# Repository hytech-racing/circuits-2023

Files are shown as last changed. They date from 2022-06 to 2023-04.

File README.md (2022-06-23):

HyTech Logo

# 2023 Circuits

Repository for all of the circuits for the 2022-2023 car.

## Getting Started with this Git Repository
1. Follow HyTech's [Software Guide](https://github.com/hytech-racing/training/tree/master/Resources).
2. Create a GitHub account if you don't already have one.
3. Download and install [GitHub Desktop](https://desktop.github.com/) (basic) or [Git CLI](https://git-scm.com/book/en/v2/Getting-Started-Installing-Git) (advanced).
    * If you are using GitHub Desktop for the first time, be sure to read the [User Guide](https://help.github.com/desktop/guides/).
    * If you are using Git for the first time, you should start off by reading a tutorial. There are many available online:
        * [Pro Git book](https://git-scm.com/book/en/v2)
        * [Atlassian Git Tutorial](https://www.atlassian.com/git/tutorials/)
    * You may want to keep a copy of [GitHub's Git Cheat Sheet](https://services.github.com/kit/downloads/github-git-cheat-sheet.pdf) as a reference.
4. Talk to your subteam lead to be added to the team within the GitHub organization.
5. Clone this repository to your computer using the URLs:
    * SSH: `git@github.com:hytech-racing/circuits-2022.git`
    * HTTPS: `https://github.com/hytech-racing/circuits-2022.git`

## Getting Started with EAGLE
1. Follow HyTech's [Software Guide](https://github.com/hytech-racing/training/tree/master/Resources).
2. Download and install [EAGLE](https://www.autodesk.com/products/eagle/overview)
3. Get the free [Educational License](https://www.autodesk.com/education/free-software/eagle) (a .edu email address is required)

## Github Software Guidelines and Electrical Designs Rules Review Process
Follow HyTech's [Github Software Guidelines](https://gtvault.sharepoint.com/:w:/r/sites/HyTechRacing2/Shared%20Documents/Electrical%20-%20All/HT06/Guidelines%20Rules%20and%20Procedures/Github%20Software%20Guide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) to understand our development flow and pull request procedure.
Follow HyTech's [Electrical Designs Rules Review Process](https://gtvault.sharepoint.com/:w:/r/sites/HyTechRacing2/Shared%20Documents/Electrical%20-%20All/HT06/Guidelines%20Rules%20and%20Procedures/Electrical%20Designs%20Ru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) to understand circuit design flow. 

## Circuit Board Versioning Scheme
* New boards must start their numbering at revision 1.
* Revision numbers must be incremented by 1 when a physical board is manufactured, but not at any other time.
* After a board is manufactured, the files corresponding to the manufactured version should not be modified.
* Circuit boards based off of a previous year's design should increment based off of the previous board's revision number.

## More Information
* [Software Guide](https://github.com/hytech-racing/training/tree/master/Resources)
* [Team Site](https://hytechracing.gatech.edu/)
* [Facebook](https://www.facebook.com/HyTechRacing/)
* [Engage](https://gatech.campuslabs.com/engage/organization/hytech-racing)

## License
This project is licensed under the GPL License v3.0. See the [LICENSE](LICENSE) file for more information.

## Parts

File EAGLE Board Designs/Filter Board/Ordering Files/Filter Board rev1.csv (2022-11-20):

Board Quantity | Ordering Quantity | Value | Reference | ATTRITION | CAPACITANCE | DKPN | MANUFACTURER | MOPN | MPN | POWER | RESISTANCE | TOLERANCE | VOLTAGE | VOLTAGE_CONTINUOUS | VOLTAGE_MAX
24 | 34 | CAPACITOR_0603_10V_0.1UF | C25, C27, C29, C31, C33, C35, C37, C39, C41, C43, C45, C47, C81, C83, C85, C87, C89, C91, C93, C95, C97, C99, C101, C103 | 42 | 0.1µF | 720-1688-1-ND | Vishay Vitramon | 77-VJ0603Y104JXQPBC | VJ0603Y104JXQPW1BC |  |  | 5% | 10V
12 | 22 | CAPACITOR_0603_10V_1UF | C26, C30, C34, C38, C42, C46, C82, C86, C90, C94, C98, C102 | 83 | 1µF | 311-1796-1-ND | Yageo | 603-CC603KRX7R6BB105 | CC0603KRX7R6BB105 |  |  | 10% | 10V
12 | 22 | CAPACITOR_0603_10V_680PF | C28, C32, C36, C40, C44, C48, C84, C88, C92, C96, C100, C104 | 83 | 680pF | 732-7757-1-ND | Würth Elektronik | 710-885012006013 | 885012006013 |  |  | 5% | 10V
16 | 26 | CAPACITOR_0603_25V_47NF | C1, C2, C3, C4, C5, C6, C7, C8, C9, C10, C49, C50, C51, C52, C53, C54 | 63 | 47nF | 478-6340-1-ND | Kyocera AVX | 581-06033C473K42ZA | 06033C473K4Z2A |  |  | 10% | 25V
2 | 4 | CONNECTOR-40__ | J4, J5 | 100 |  | SAM8560-ND | Samtec | 200-EHT12001SD | EHT-120-01-S-D
12 | 14 | MAX7400 | U6, U7, U8, U9, U10, U11, U19, U20, U21, U22, U23, U24 | 17 |  | MAX7400CSA+-ND | Maxim Integrated | 700-MAX7400CSA | MAX7400CSA+
12 | 22 | RESISTOR_0603_13K | R4, R9, R11, R13, R15, R17, R27, R35, R37, R39, R41, R43 | 83 |  | P13KBECT-ND | Panasonic Electronic Components | 667-ERA-3ARW133V | ERA-3ARW133V | 0.1W | 13k | 0.05% |  | 75V | 150V
28 | 38 | RESISTOR_0603_3.3K | R1, R2, R3, R5, R6, R7, R8, R10, R12, R14, R16, R18, R19, R20, R21, R22, R23, R24, R25, R26, R28, R29, R30, R36, R38, R40, R42, R44 | 36 |  | P20340TR-ND | Panasonic Electronic Components | 667-ERJ-PB3D3301V | ERJ-PB3D3301V | 0.2W | 3.3k | 0.5% |  | 25.69V | 150

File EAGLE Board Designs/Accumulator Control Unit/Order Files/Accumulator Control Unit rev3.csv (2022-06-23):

Board Quantity | Ordering Quantity | Value | Reference | ATTRITION | CAPACITANCE | COLOR | CURRENT | DKPN | GAUGE | MANUFACTURER | MOPN | MPN | POWER | RESISTANCE | TEENSY | TOLERANCE | VOLTAGE | VOLTAGE_CONTINUOUS | VOLTAGE_MAX
1 | 3 | ADG1423 | U100 | 200 |  |  |  | ADG1423BRMZ-REEL7CT-ND |  | Analog Devices Inc. | 584-ADG1423BRMZ | ADG1423BRMZ
1 | 3 | ADM8316WBX30 | U7 | 200 |  |  |  | ADM8316WBX30ARJZR7TR-ND |  | Analog Devices Inc. | 584-M8316WBX30ARJZR7 | ADM8316WBX30ARJZR7
21 | 31 | CAPACITOR_0603_10V_0.1UF | C3, C5, C9, C10, C11, C13, C14, C15, C16, C17, C18, C19, C21, C22, C26, C27, C28, C30, C31, C34, C38 | 48 | 0.1µF |  |  | 720-1688-1-ND |  | Vishay Vitramon | 77-VJ0603Y104JXQPBC | VJ0603Y104JXQPW1BC |  |  |  | 5% | 10V
3 | 13 | CAPACITOR_0603_10V_10NF | C1, C6, C100 | 333 | 10nF |  |  | 311-4054-1-ND |  | Yageo | 603-CC603KRX7R6BB103 | CC0603KRX7R6BB103 |  |  |  | 10% | 10V
2 | 12 | CAPACITOR_0603_10V_1UF | C37, C39 | 500 | 1µF |  |  | 311-1796-1-ND |  | Yageo | 603-CC603KRX7R6BB105 | CC0603KRX7R6BB105 |  |  |  | 10% | 10V
1 | 11 | CAPACITOR_0603_10V_4.7NF | C25 | 1000 | 4.7nF |  |  | 732-7931-1-ND |  | Würth Elektronik | 710-885012206012 | 885012206012 |  |  |  | 10% | 10V
2 | 12 | CAPACITOR_0603_10V_4.7UF | C36, C103 | 500 | 4.7µF |  |  | 1276-1044-1-ND |  | Samsung Electro-Mechanics | 187-CL10A475KP8NNNC | CL10A475KP8NNNC |  |  |  | 10% | 10V
4 | 14 | CAPACITOR_0603_10V_680PF | C4, C12, C23, C32 | 250 | 680pF |  |  | 732-7757-1-ND |  | Würth Elektronik | 710-885012006013 | 885012006013 |  |  |  | 5% | 10V
6 | 16 | CAPACITOR_0603_25V_0.1UF | C2, C8, C20, C29, C35, C102 | 167 | 0.1µF |  |  | 1276-1006-1-ND |  | Samsung Electro-Mechanics | 187-CL10B104KA8NNNC | CL10B104KA8NNNC |  |  |  | 10% | 25V
2 | 12 | CAPACITOR_0603_25V_10UF | C24, C33 | 500 | 10µF |  |  | 490-7202-1-ND |  | Murata Electronics | 81-GRM188R61E106MA3D | GRM188R61E106MA73D |  |  |  | 20% | 25V
2 | 12 | CAPACITOR_0603_25V_1UF | C101, C104 | 500 | 1µF |  |  | 1276-1184-1-ND |  | Samsung Electro-Mechanics | 187-CL10B105KA8NNNC | CL10B105KA8NNNC |  |  |  | 10% | 25V
1 | 3 | CONNECTOR-12_MF_T_V_ | J5 | 200 |  |  |  |  |  | MOLEX |  | 430451214
1 | 3 | CONNECTOR-14_MF_T_V_ | J3 | 200 |  |  |  |  |  | MOLEX |  | 430451414
1 | 3 | CONNECTOR-2_MF_T_V_ | J1 | 200 |  |  |  |  |  | MOLEX |  | 436500217
1 | 3 | CONNECTOR-8_MF_T_V_ | J2 | 200 |  |  |  |  |  | MOLEX |  | 430450814
1 | 3 | CONNECTOR-8_S_S | J100 | 200 |  |  |  | S7107-ND |  | Sullins Connector Solutions |  | PPPC042LFBN-RC
1 | 3 | CONNECTOR-CAN_μF_S_RA_ | J6 | 200 |  |  |  | WM1832CT-ND |  | Molex | 538-43045-0411 | 0430450411
24 | 48 | CRIMP_MICROFIT_20-24 | O4, O5, O6, O7, O8, O9, O10, O11, O12, O13, O14, O15, O16, O17, O18, O19, O20, O21, O22, O23, O24, O25, O26, O27 | 100 |  |  |  | WM2776CT-ND | 20-24 | Molex | 538-43030-0003 | 0430300003
2 | 4 | FUSE_0603_.75A | F1, F2 | 100 |  |  | 0.75A | 507-2159-2-ND |  | Bel Fuse | 530-0686F0750-01 | 0686F0750-01 |  |  |  |  | 63V
1 | 3 | FUSE_HOLDER_MINIBLADEPTH | XF1 | 200 |  |  |  | 36-3568-ND |  | Keystone | 534-3568 | 3568
1 | 2 | FUSE_MINI_BLADE_1 | O28 | 100 |  |  |  | 2298-ANM58-1A-ND |  | OptiFuse |  | ANM58-1A
1 | 3 | JUMPER__1X02 | J4 | 200 |  |  |  | S1011EC-02-ND |  | Sullins Connector Solutions |  | PRPC002SAAN-RC
2 | 12 | LED_0603_BLUE | 5V, WATCHDOG | 500 |  | Blue |  | 754-1789-1-ND |  | Kingbright | 604-APT1608VBC/D | APT1608VBC/D
3 | 13 | LED_0603_GREEN | 3.3V, AMS_OK, TSAL_GREEN | 333 |  | Green |  | 754-1790-1-ND |  | Kingbright | 604-APT1608ZGCK | APT1608ZGCK
1 | 11 | LED_0603_ORANGE | IMD_OK | 1000 |  | Orange |  | 754-1120-1-ND |  | Kingbright | 604-APT1608SECK | APT1608SECK
4 | 14 | LED_0603_RED | 12V, PRECHARGE_OK, TEENSY_OK, TSAL_RED | 250 |  | Red |  | 754-1786-1-ND |  | Kingbright | 604-APT1608SECKJ3PRV | APT1608SECK/J3-PRV
1 | 2 | LED_0603_YELLOW | OKHS | 100 |  | Yellow |  | 754-1788-1-ND |  | Kingbright | 604-APT1608SYCK/J3-PRV | APT1608SYCK/J3-PRV
1 | 3 | LM555 | U101 | 200 |  |  |  | LM555CMX/NOPBCT-ND |  | Texas Instruments | 926-LM555CMX/NOPB | LM555CMX/NOPB
3 | 5 | LOGICGATE_AND_DCK3 | U12, U14, U16 | 67 |  |  |  | 296-SN74LVC1G08DCK3TR-ND |  | Texas Instruments | 595-SN74LVC1G08DCK3 | SN74LVC1G08DCK3
1 | 3 | LOGICGATE_BUFFER | U6 | 200 |  |  |  | 296-26604-2-ND |  | Texas Instruments | 595-SN74LVC1G34DCKT | SN74LVC1G34DCKT
1 | 3 | LTC6820 | U5 | 200 |  |  |  |  |  | Analog Devices |  | LTC6820IMS#PBF
4 | 6 | MAX7404 | U4, U10, U19, U25 | 50 |  |  |  | MAX7404CSA+-ND |  | Maxim Integrated | 700-MAX7404CSA | MAX7404CSA+
12 | 14 | OPAMP_1_CHANNEL_OPA991 | U3, U9, U11, U13, U15, U17, U18, U20, U21, U22, U23, U24 | 17 |  |  |  | 296-OPA991IDCKRCT-ND |  | Texas Instruments | 595-OPA991IDCKR | OPA991IDCKR
1 | 2 | RECEPTACLE-12_MICROFIT | O3 | 100 |  |  |  | WM1788-ND |  | Molex | 538-43025-1200 | 430251200
1 | 2 | RECEPTACLE-14_MICROFIT | O2 | 100 |  |  |  | 0430251400 |  | Molex | 538-43025-1400 | 430251400
1 | 2 | RECEPTACLE-8_MICROFIT | O1 | 100 |  |  |  | WM13210-ND |  | Molex | 538-43025-0808 | 0430250808
3 | 5 | RELAY_SOLIDSTATE_NO | U1, U2, U8 | 67 |  |  |  |  |  |  |  | AQY214EHA
5 | 15 | RESISTOR_0603_ | R4, R20, R79, R108, R110 | 200 |  |  |  | P30KBDCT-ND |  | Panasonic Electronic Components | 667-ERA-3ARB303V | ERA-3ARB303V | 0.1W | 30k |  | 0.1% |  | 54.77V | 75V
1 | 11 | RESISTOR_0603_1.4K | R58 | 1000 |  |  |  | 311-2465-1-ND |  | Yageo | 603-RT0603DRE071K4L | RT0603DRE071K4L | 0.1W | 1.4K |  | 0.5% |  | 75V | 75V
4 | 14 | RESISTOR_0603_10 | R13, R18, R103, R104 | 250 |  |  |  | 311-10.0HRCT-ND |  | Yageo | 603-RC0603FR-0710RL | RC0603FR-0710RL | 0.1W | 10 |  | 1% |  | 1V | 75V
2 | 12 | RESISTOR_0603_10.2K | R41, R48 | 500 |  |  |  | P10.2KDBCT-ND |  | Panasonic Electronic Components | 667-ERA-3AEB1022V | ERA-3AEB1022V | 0.1W | 10.2k |  | 0.1% |  | 31.94V | 75V
4 | 14 | RESISTOR_0603_10.5K | R65, R68, R72, R76 | 250 |  |  |  | P10.5KDBCT-ND |  | Panasonic Electronic Components | 677-ERA-3AEB1052V | ERA-3AEB1052V | 0.1W | 10.5k |  | 0.1% |  | 32.40V | 75V
27 | 37 | RESISTOR_0603_10K | R6, R12, R14, R17, R22, R26, R27, R29, R30, R37, R42, R43, R44, R50, R52, R55, R59, R69, R71, R73, R77, R81, R82, R100, R101, R102, R106 | 37 |  |  |  | 311-10.0KHRCT-ND |  | Yageo | 603-RC0603FR-0710KL | RC0603FR-0710KL | 0.1W | 10k |  | 1% |  | 31.62V | 75V
1 | 11 | RESISTOR_0603_11.3K | R70 | 1000 |  |  |  | P11.3KDBCT-ND |  | Panasonic Electronic Components | 667-ERA-3AEB1132V | ERA-3AEB1132V | 0.1W | 11.3k |  | 0.1% |  | 33.62V | 75V
7 | 17 | RESISTOR_0603_11.5K | R38, R51, R53, R66, R67, R74, R75 | 143 |  |  |  | P11.5KDBCT-ND |  | Panasonic Electronic Components | 667-ERA-3AEB1152V | ERA-3AEB1152V | 0.1W | 11.5k |  | 0.1% |  | 33.91V | 75V
1 | 11 | RESISTOR_0603_120 | R1 | 1000 |  |  |  | P120DBCT-ND |  | Panasonic Electronic Components | 667-ERA-3AEB121V | ERA-3AEB121V | 0.1W | 120 |  | 0.1% |  | 3.46V | 75V
7 | 17 | RESISTOR_0603_12K | R5, R23, R31, R56, R78, R80, R107 | 143 |  |  |  | 311-12.0KHRCT-ND |  | Yageo | 603-RC0603FR-0712KL | RC0603FR-0712KL | 0.1W | 12k |  | 1% |  | 34.64V | 75V
1 | 11 | RESISTOR_0603_15K | R21 | 1000 |  |  |  | P15KBDCT-ND |  | Panasonic Electronic Components | 667-ERA-3ARB153V | ERA-3ARB153V | 0.1W | 15k |  | 0.1% |  | 38.73V | 75V
1 | 11 | RESISTOR_0603_18.7K | R109 | 1000 |  |  |  | 311-18.7KHRCT-ND |  | Yageo | 603-RC0603FR-0718K7L | RC0603FR-0718K7L | 0.1W | 18.7k |  | 1% |  | 43.24V | 75V
9 | 19 | RESISTOR_0603_1K | R3, R9, R10, R11, R16, R19, R24, R25, R57 | 111 |  |  |  | 311-1.00KHRCT-ND |  | Yageo | 603-RC0603FR-071KL | RC0603FR-071KL | 0.1W | 1k |  | 1% |  | 10.00V | 75V
1 | 11 | RESISTOR_0603_2.2K | R15 | 1000 |  |  |  | 13-RC0603DR-072K2LCT-ND |  | Yageo | 603-RC0603DR-072K2L | RC0603DR-072K2L | 0.1W | 2.2k |  | 0.5% |  | 75V | 75V
1 | 11 | RESISTOR_0603_215K | R46 | 1000 |  |  |  | P215KDBCT-ND |  | Panasonic Electronic Components | 667-ERA-3AEB2153V | ERA-3AEB2153V | 0.1W | 215k |  | 0.1% |  | 75V | 75V
7 | 17 | RESISTOR_0603_2K | R2, R7, R8, R32, R33, R61, R62 | 143 |  |  |  | P2.0KBDCT-ND |  | Panasonic Electronic Components | 667-ERA-3ARB202V | ERA-3ARB202V | 0.1W | 2k |  | 0.1% |  | 14.14V | 75V
2 | 12 | RESISTOR_0603_4.12K | R49, R63 | 500 |  |  |  | P4.12KDBCT-ND |  | Panasonic Electronic Components | 667-ERA-3AEB4121V | ERA-3AEB4121V | 0.1W | 4.12k |  | 0.1% |  | 20.30V | 75V
1 | 11 | RESISTOR_0603_43K | R105 | 1000 |  |  |  | 311-43.0KHRCT-ND |  | Yageo | 603-RC0603FR-0743KL | RC0603FR-0743KL | 0.1W | 43k |  | 1% |  | 65.57V | 75V
3 | 13 | RESISTOR_0603_470 | R28, R34, R35 | 333 |  |  |  | P470BYCT-ND |  | Panasonic Electronic Components | 667-ERJ-PA3F4700V | ERJ-PA3F4700V | 0.25W | 470 |  | 1% |  | 10.84V | 150V
2 | 12 | RESISTOR_0603_60.4 | R36, R60 | 500 |  |  |  | 311-60.4HRCT-ND |  | Yageo | 603-RC0603FR-0760R4L | RC0603FR-0760R4L | 0.1W | 60.4 |  | 1% |  | 2.48V | 75V
1 | 11 | RESISTOR_0603_84.5K | R39 | 1000 |  |  |  | P84.5KDBCT-ND |  | Panasonic Electronic Components | 667-ERA-3AEB8452V | ERA-3AEB8452V | 0.1W | 84.5k |  | 0.1% |  | 75V | 75V
5 | 15 | RESISTOR_0603_DNP | R40, R45, R47, R54, R64 | 200 |  |  |  |  |  |  |  |  |  | DNP
1 | 3 | TCAN1051HQV-Q1 | U27 | 200 |  |  |  | 296-49935-1-ND |  | Texas Instruments | 595-TCAN1051HGVDQ1 | TCAN1051HGVDRQ1
1 | 3 | TEENSY_4.0 | A2 | 200 |  |  |  |  |  |  |  |  |  |  | 4.0
17 | 19 | TEST_POINT | BSPD_CURRENT, CURRENT_REF, CURRENT_SENSE, PACK+_OUT_TEST, PRECHARGE_OK_TEST, TD+, TD-, TP_3.3V, TP_5V, TP_12V, TP_AMS_OK, TP_GND, TP_IMD_OK, TP_TSAL_GREEN, TP_TSAL_RED, TS+_OUT_TEST, WATCHDOG_OK | 12 |  |  |  | 36-5015CT-ND |  | Keystone Electronics | 534-5015 | 5015
1 | 3 | TRANSFORMER_HM2112ZNLT_AIRGAP | T1 | 200 |  |  |  | 1840-1036-1-ND |  | Pulse Electronics | 673-HM2112ZNLT | HM2112ZNLT
4 | 6 | TRANSISTOR_N_MOS__PMV15ENEA | Q1, Q2, Q100, Q101 | 50 |  |  |  | 1727-8588-1-ND |  | Nexperia USA Inc. | 771-PMV15ENEAR | PMV15ENEAR
8 | 10 | TVS_15V | D3, D7, D8, D9, D10, D11, D100, D101 | 25 |  |  |  | GSOT15-E3-08CT-ND |  | Vishay General Semiconductor - Diodes Division | 78-GSOT15-E3-08 | GSOT15-E3-08 |  |  |  |  | 15V
2 | 4 | TVS_8V | D2, D4 | 100 |  |  |  | GSOT08-E3-08-ND |  | Vishay General Semiconductor - Diodes Division | 78-GSOT08-E3-08 | GSOT08-E3-08 |  |  |  |  | 8V
1 | 3 | VOLTAGE_REGULATOR_MODULE_OKI-78SR_5V | A1 | 200 |  |  |  | 811-2196-5-ND |  | Murata Power Solutions Inc. | 580-OKI78SR5/1.5W36C | OKI-78SR-5/1.5-W36-C
1 | 3 | VOLTAGE_REGULATOR_SOT223_3.3V | U26 | 200 |  |  |  | 497-17239-1-ND |  | STMicroelectronics | 511-LDL1117S33R | LDL1117S33R

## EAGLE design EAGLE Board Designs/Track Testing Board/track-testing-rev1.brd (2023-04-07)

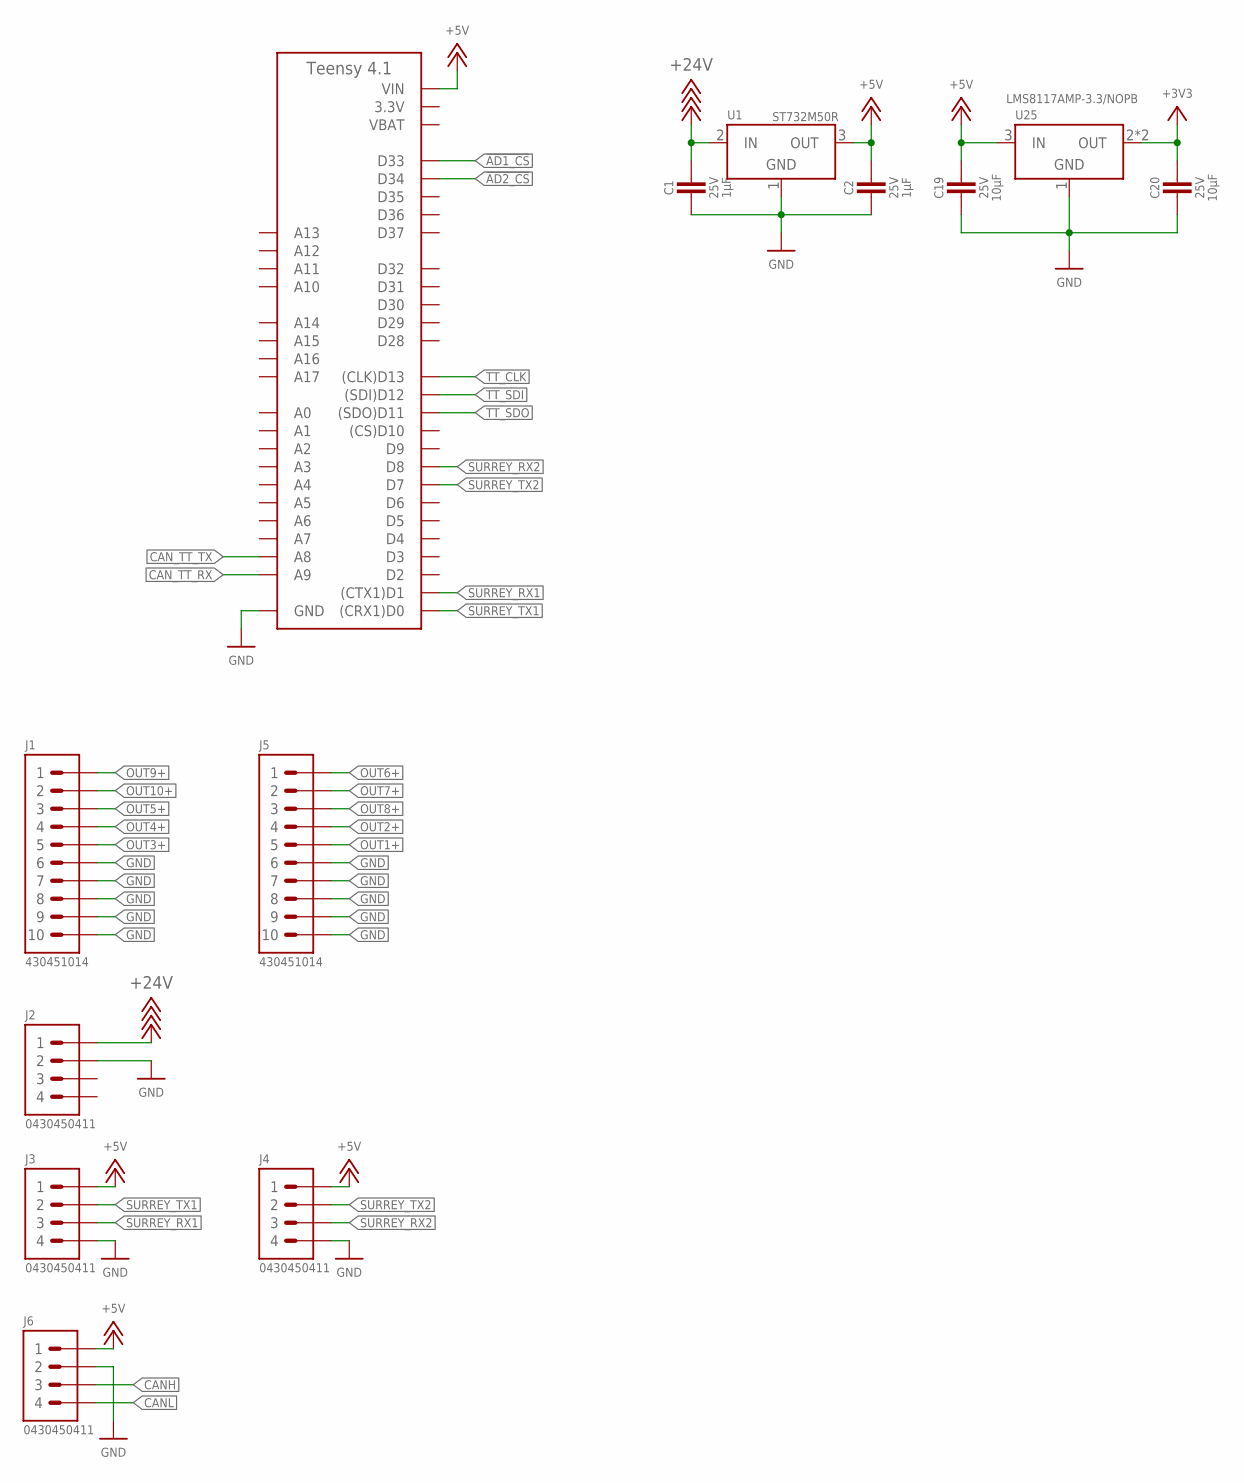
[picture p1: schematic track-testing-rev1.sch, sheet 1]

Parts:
A1: TEENSY_4.1; TEENSY_LONG_EXT
C1, C2: CAPACITOR_0603_25V_1UF; 0603-CAP
C19, C20: CAPACITOR_0603_25V_10UF; 0603-CAP
J1, J5: CONNECTOR-10_MF_T_V_; MOLEX_MICROFIT_PTH_VERTICAL_10_DUAL
J2, J3, J4, J6: CONNECTOR-4_μF_S_RA_; MOLEX_MICROFIT_SMD_RIGHTANGLE_04_DUAL
U1: VOLTAGE_REGULATOR_SOT-23-5_5V; SOT-23-5
U25: VOLTAGE_REGULATOR_SOT-223_3.3V; SOT-223

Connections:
3.3V: A1.3V3 (3.3V), A1.3V3@2 (3.3V), A1.3V3@3 (3.3V)
!AD1_CS: A1.D33; also elsewhere on the board
!AD2_CS: A1.D34; also elsewhere on the board
+3V3: C20.1, U25.2 (OUT), U25.4 (OUT); also elsewhere on the board
+5V: A1.VIN, C2.1, C19.1, J3.1, J4.1, J6.1, U1.3 (OUT), U25.3 (IN); also elsewhere on the board
+24V: C1.1, J2.1, U1.2 (IN)
CANH: J6.3; also elsewhere on the board
CANL: J6.4; also elsewhere on the board
CAN_TT_RX: A1.D23 (A9); also elsewhere on the board
CAN_TT_TX: A1.D22 (A8); also elsewhere on the board
GND: A1.AGND/GND (GND), A1.GND, A1.GND@2 (GND), C1.2, C2.2, C19.2, C20.2, J1.6, J1.7, J1.8, J1.9, J1.10, J2.2, J3.4, J4.4, J5.6, J5.7, J5.8, J5.9, J5.10, J6.2, U1.1 (GND), U25.1 (GND); also elsewhere on the board
OUT1+: J5.5; also elsewhere on the board
OUT2+: J5.4; also elsewhere on the board
OUT3+: J1.5; also elsewhere on the board
OUT4+: J1.4; also elsewhere on the board
OUT5+: J1.3; also elsewhere on the board
OUT6+: J5.1; also elsewhere on the board
OUT7+: J5.2; also elsewhere on the board
OUT8+: J5.3; also elsewhere on the board
OUT9+: J1.1; also elsewhere on the board
OUT10+: J1.2; also elsewhere on the board
SURREY_RX1: A1.D1 ((CTX1)D1), J3.3
SURREY_RX2: A1.D8, J4.3
SURREY_TX1: A1.D0 ((CRX1)D0), J3.2
SURREY_TX2: A1.D7, J4.2
TT_CLK: A1.D13 ((CLK)D13); also elsewhere on the board
TT_SDI: A1.D12 ((SDI)D12); also elsewhere on the board
TT_SDO: A1.D11 ((SDO)D11); also elsewhere on the board
VBAT: A1.VBAT

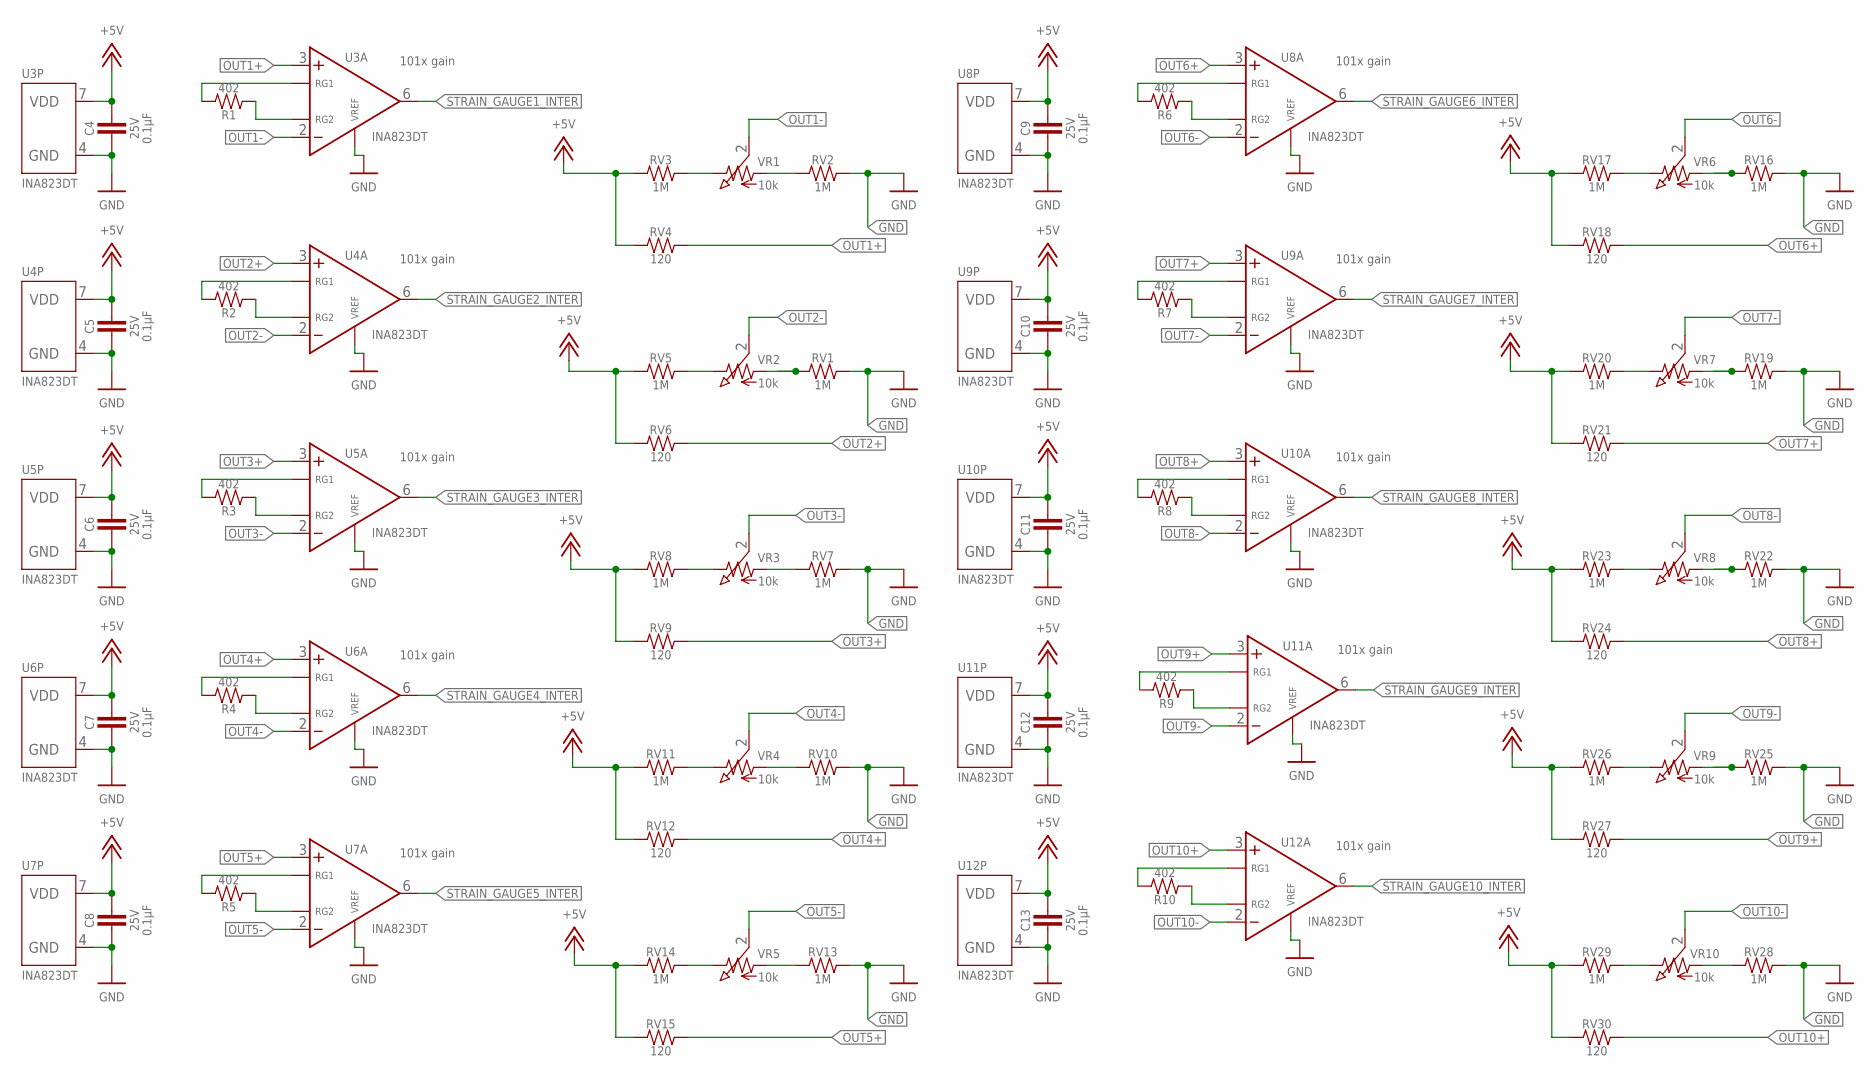
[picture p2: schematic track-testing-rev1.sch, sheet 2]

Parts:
C4, C5, C6, C7, C8, C9, C10, C11, C12, C13: CAPACITOR_0603_25V_0.1UF; 0603-CAP
R1, R2, R3, R4, R5, R6, R7, R8, R9, R10: RESISTOR_0603_402; 0603-RES
RV1, RV2, RV3, RV5, RV7, RV8, RV10, RV11, RV13, RV14, RV16, RV17, RV19, RV20, RV22, RV23, RV25, RV26, RV28, RV29: 1M; 0603-RES
RV4, RV6, RV9, RV12, RV15, RV18, RV21, RV24, RV27, RV30: 120; 0603-RES
U3, U4, U5, U6, U7, U8, U9, U10, U11, U12: INA823DT; SOIC-08(NARROW,0.15")
VR1, VR2, VR3, VR4, VR5, VR6, VR7, VR8, VR9, VR10: RESISTOR_TRIMPOT_10K_3362P; 3362P

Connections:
+5V: C4.1, C5.1, C6.1, C7.1, C8.1, C9.1, C10.1, C11.1, C12.1, C13.1, RV3.1, RV4.1, RV5.1, RV6.1, RV8.1, RV9.1, RV11.1, RV12.1, RV14.1, RV15.1, RV17.1, RV18.1, RV20.1, RV21.1, RV23.1, RV24.1, RV26.1, RV27.1, RV29.1, RV30.1, U3.7 (VDD), U4.7 (VDD), U5.7 (VDD), U6.7 (VDD), U7.7 (VDD), U8.7 (VDD), U9.7 (VDD), U10.7 (VDD), U11.7 (VDD), U12.7 (VDD); also elsewhere on the board
GND: C4.2, C5.2, C6.2, C7.2, C8.2, C9.2, C10.2, C11.2, C12.2, C13.2, RV1.2, RV2.2, RV7.2, RV10.2, RV13.2, RV16.2, RV19.2, RV22.2, RV25.2, RV28.2, U3.4 (GND), U3.5 (VREF), U4.4 (GND), U4.5 (VREF), U5.4 (GND), U5.5 (VREF), U6.4 (GND), U6.5 (VREF), U7.4 (GND), U7.5 (VREF), U8.4 (GND), U8.5 (VREF), U9.4 (GND), U9.5 (VREF), U10.4 (GND), U10.5 (VREF), U11.4 (GND), U11.5 (VREF), U12.4 (GND), U12.5 (VREF); also elsewhere on the board
unnamed: R2.2, U4.1 (RG1)
unnamed: R1.2, U3.1 (RG1)
unnamed: R1.1, U3.8 (RG2)
unnamed: R2.1, U4.8 (RG2)
unnamed: R3.2, U5.1 (RG1)
unnamed: R6.2, U8.1 (RG1)
unnamed: R3.1, U5.8 (RG2)
unnamed: R6.1, U8.8 (RG2)
unnamed: R4.2, U6.1 (RG1)
unnamed: R7.2, U9.1 (RG1)
unnamed: R4.1, U6.8 (RG2)
unnamed: R5.2, U7.1 (RG1)
unnamed: R5.1, U7.8 (RG2)
unnamed: R7.1, U9.8 (RG2)
unnamed: R8.2, U10.1 (RG1)
unnamed: R8.1, U10.8 (RG2)
unnamed: R9.2, U11.1 (RG1)
unnamed: R9.1, U11.8 (RG2)
unnamed: R10.2, U12.1 (RG1)
unnamed: R10.1, U12.8 (RG2)
unnamed: RV2.1, VR1.1
unnamed: RV3.2, VR1.3 (2)
unnamed: RV1.1, VR2.1
unnamed: RV5.2, VR2.3 (2)
unnamed: RV11.2, VR4.3 (2)
unnamed: RV7.1, VR3.1
unnamed: RV8.2, VR3.3 (2)
unnamed: RV10.1, VR4.1
unnamed: RV14.2, VR5.3 (2)
unnamed: RV13.1, VR5.1
unnamed: RV16.1, VR6.1
unnamed: RV17.2, VR6.3 (2)
unnamed: RV19.1, VR7.1
unnamed: RV20.2, VR7.3 (2)
unnamed: RV22.1, VR8.1
unnamed: RV23.2, VR8.3 (2)
unnamed: RV25.1, VR9.1
unnamed: RV26.2, VR9.3 (2)
unnamed: RV28.1, VR10.1
unnamed: RV29.2, VR10.3 (2)
OUT1+: RV4.2, U3.3 (VIN+); also elsewhere on the board
OUT1-: U3.2 (VIN-), VR1.2 (3)
OUT2+: RV6.2, U4.3 (VIN+); also elsewhere on the board
OUT2-: U4.2 (VIN-), VR2.2 (3)
OUT3+: RV9.2, U5.3 (VIN+); also elsewhere on the board
OUT3-: U5.2 (VIN-), VR3.2 (3)
OUT4+: RV12.2, U6.3 (VIN+); also elsewhere on the board
OUT4-: U6.2 (VIN-), VR4.2 (3)
OUT5+: RV15.2, U7.3 (VIN+); also elsewhere on the board
OUT5-: U7.2 (VIN-), VR5.2 (3)
OUT6+: RV18.2, U8.3 (VIN+); also elsewhere on the board
OUT6-: U8.2 (VIN-), VR6.2 (3)
OUT7+: RV21.2, U9.3 (VIN+); also elsewhere on the board
OUT7-: U9.2 (VIN-), VR7.2 (3)
OUT8+: RV24.2, U10.3 (VIN+); also elsewhere on the board
OUT8-: U10.2 (VIN-), VR8.2 (3)
OUT9+: RV27.2, U11.3 (VIN+); also elsewhere on the board
OUT9-: U11.2 (VIN-), VR9.2 (3)
OUT10+: RV30.2, U12.3 (VIN+); also elsewhere on the board
OUT10-: U12.2 (VIN-), VR10.2 (3)
STRAIN_GAUGE1_INTER: U3.6 (VOUT); also elsewhere on the board
STRAIN_GAUGE2_INTER: U4.6 (VOUT); also elsewhere on the board
STRAIN_GAUGE3_INTER: U5.6 (VOUT); also elsewhere on the board
STRAIN_GAUGE4_INTER: U6.6 (VOUT); also elsewhere on the board
STRAIN_GAUGE5_INTER: U7.6 (VOUT); also elsewhere on the board
STRAIN_GAUGE6_INTER: U8.6 (VOUT); also elsewhere on the board
STRAIN_GAUGE7_INTER: U9.6 (VOUT); also elsewhere on the board
STRAIN_GAUGE8_INTER: U10.6 (VOUT); also elsewhere on the board
STRAIN_GAUGE9_INTER: U11.6 (VOUT); also elsewhere on the board
STRAIN_GAUGE10_INTER: U12.6 (VOUT); also elsewhere on the board

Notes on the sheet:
101x gain

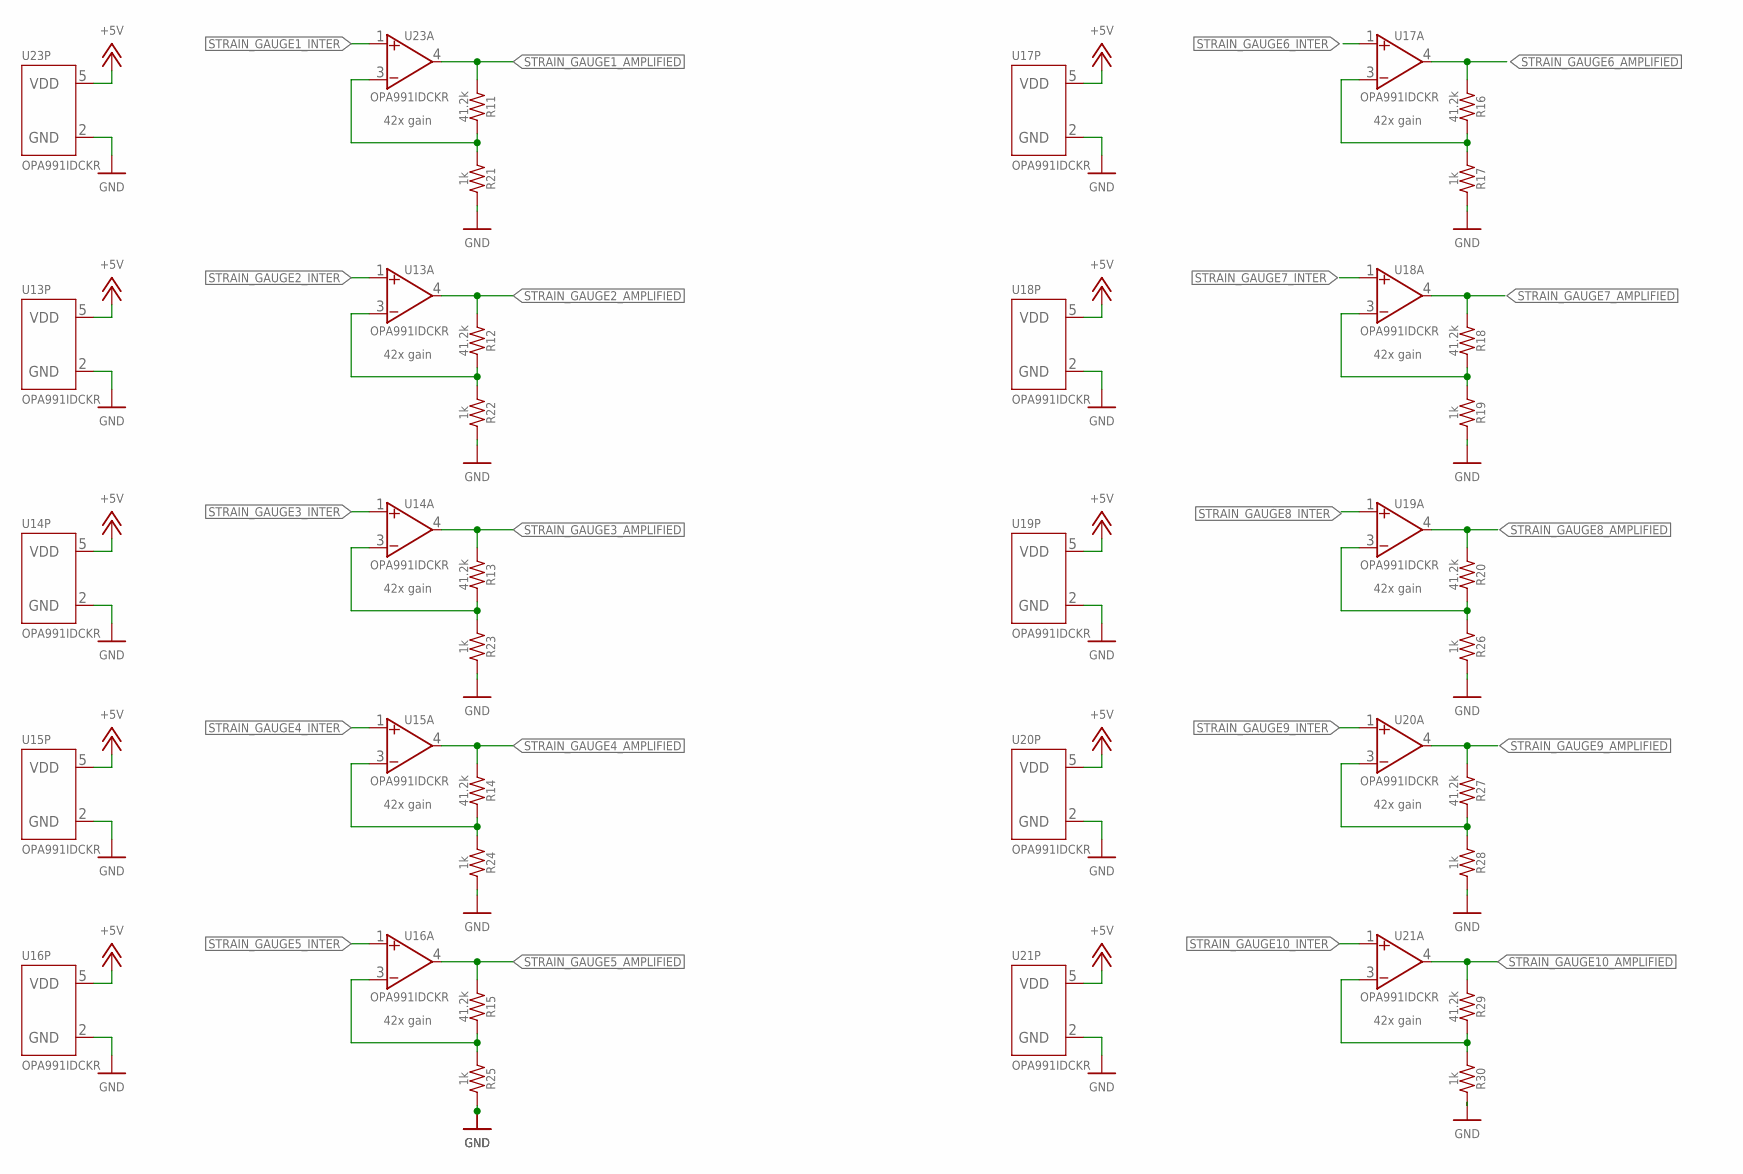
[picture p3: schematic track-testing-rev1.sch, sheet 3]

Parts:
R11, R12, R13, R14, R15, R16, R18, R20, R27, R29: RESISTOR_0603_41.2K; 0603-RES
R17, R19, R21, R22, R23, R24, R25, R26, R28, R30: RESISTOR_0603_1K; 0603-RES
U13, U14, U15, U16, U17, U18, U19, U20, U21, U23: OPAMP_1_CHANNEL_OPA991; SC-70-5

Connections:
+5V: U13.5 (VDD), U14.5 (VDD), U15.5 (VDD), U16.5 (VDD), U17.5 (VDD), U18.5 (VDD), U19.5 (VDD), U20.5 (VDD), U21.5 (VDD), U23.5 (VDD); also elsewhere on the board
GND: R17.2, R19.2, R21.2, R22.2, R23.2, R24.2, R25.2, R26.2, R28.2, R30.2, U13.2 (GND), U14.2 (GND), U15.2 (GND), U16.2 (GND), U17.2 (GND), U18.2 (GND), U19.2 (GND), U20.2 (GND), U21.2 (GND), U23.2 (GND); also elsewhere on the board
unnamed: R12.2, R22.1, U13.3 (VIN-)
unnamed: R11.2, R21.1, U23.3 (VIN-)
unnamed: R13.2, R23.1, U14.3 (VIN-)
unnamed: R14.2, R24.1, U15.3 (VIN-)
unnamed: R15.2, R25.1, U16.3 (VIN-)
unnamed: R16.2, R17.1, U17.3 (VIN-)
unnamed: R18.2, R19.1, U18.3 (VIN-)
unnamed: R20.2, R26.1, U19.3 (VIN-)
unnamed: R27.2, R28.1, U20.3 (VIN-)
unnamed: R29.2, R30.1, U21.3 (VIN-)
STRAIN_GAUGE1_AMPLIFIED: R11.1, U23.4 (VOUT); also elsewhere on the board
STRAIN_GAUGE1_INTER: U23.1 (VIN+); also elsewhere on the board
STRAIN_GAUGE2_AMPLIFIED: R12.1, U13.4 (VOUT); also elsewhere on the board
STRAIN_GAUGE2_INTER: U13.1 (VIN+); also elsewhere on the board
STRAIN_GAUGE3_AMPLIFIED: R13.1, U14.4 (VOUT); also elsewhere on the board
STRAIN_GAUGE3_INTER: U14.1 (VIN+); also elsewhere on the board
STRAIN_GAUGE4_AMPLIFIED: R14.1, U15.4 (VOUT); also elsewhere on the board
STRAIN_GAUGE4_INTER: U15.1 (VIN+); also elsewhere on the board
STRAIN_GAUGE5_AMPLIFIED: R15.1, U16.4 (VOUT); also elsewhere on the board
STRAIN_GAUGE5_INTER: U16.1 (VIN+); also elsewhere on the board
STRAIN_GAUGE6_AMPLIFIED: R16.1, U17.4 (VOUT); also elsewhere on the board
STRAIN_GAUGE6_INTER: U17.1 (VIN+); also elsewhere on the board
STRAIN_GAUGE7_AMPLIFIED: R18.1, U18.4 (VOUT); also elsewhere on the board
STRAIN_GAUGE7_INTER: U18.1 (VIN+); also elsewhere on the board
STRAIN_GAUGE8_AMPLIFIED: R20.1, U19.4 (VOUT); also elsewhere on the board
STRAIN_GAUGE8_INTER: U19.1 (VIN+); also elsewhere on the board
STRAIN_GAUGE9_AMPLIFIED: R27.1, U20.4 (VOUT); also elsewhere on the board
STRAIN_GAUGE9_INTER: U20.1 (VIN+); also elsewhere on the board
STRAIN_GAUGE10_AMPLIFIED: R29.1, U21.4 (VOUT); also elsewhere on the board
STRAIN_GAUGE10_INTER: U21.1 (VIN+); also elsewhere on the board

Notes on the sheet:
42x gain

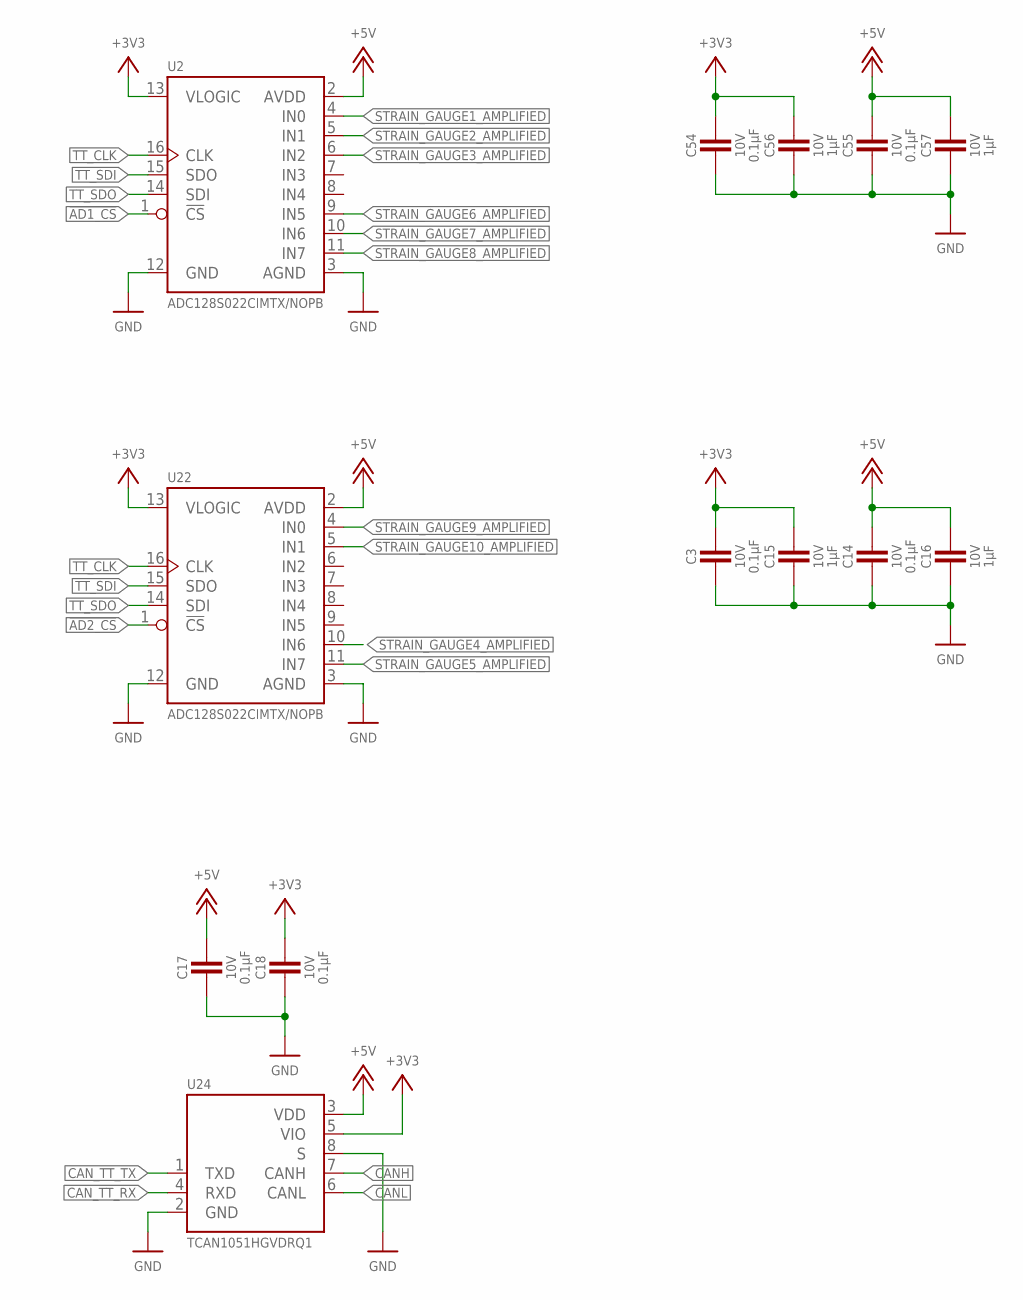
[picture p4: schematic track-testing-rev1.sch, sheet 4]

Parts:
C3, C14, C17, C18, C54, C55: CAPACITOR_0603_10V_0.1UF; 0603-CAP
C15, C16, C56, C57: CAPACITOR_0603_10V_1UF; 0603-CAP
U2, U22: ADC128S022; TSSOP-16
U24: TCAN1051HQV-Q1; SOIC-08(NARROW,0.15")

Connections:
!AD1_CS: U2.1 (!CS!); also elsewhere on the board
!AD2_CS: U22.1 (!CS!); also elsewhere on the board
+3V3: C3.1, C15.1, C18.1, C54.1, C56.1, U2.13 (VLOGIC), U22.13 (VLOGIC), U24.5 (VIO); also elsewhere on the board
+5V: C14.1, C16.1, C17.1, C55.1, C57.1, U2.2 (AVDD), U22.2 (AVDD), U24.3 (VDD); also elsewhere on the board
CANH: U24.7 (CANH); also elsewhere on the board
CANL: U24.6 (CANL); also elsewhere on the board
CAN_TT_RX: U24.4 (RXD); also elsewhere on the board
CAN_TT_TX: U24.1 (TXD); also elsewhere on the board
GND: C3.2, C14.2, C15.2, C16.2, C17.2, C18.2, C54.2, C55.2, C56.2, C57.2, U2.3 (AGND), U2.12 (GND), U22.3 (AGND), U22.12 (GND), U24.2 (GND), U24.8 (S); also elsewhere on the board
STRAIN_GAUGE1_AMPLIFIED: U2.4 (IN0); also elsewhere on the board
STRAIN_GAUGE2_AMPLIFIED: U2.5 (IN1); also elsewhere on the board
STRAIN_GAUGE3_AMPLIFIED: U2.6 (IN2); also elsewhere on the board
STRAIN_GAUGE4_AMPLIFIED: U22.10 (IN6); also elsewhere on the board
STRAIN_GAUGE5_AMPLIFIED: U22.11 (IN7); also elsewhere on the board
STRAIN_GAUGE6_AMPLIFIED: U2.9 (IN5); also elsewhere on the board
STRAIN_GAUGE7_AMPLIFIED: U2.10 (IN6); also elsewhere on the board
STRAIN_GAUGE8_AMPLIFIED: U2.11 (IN7); also elsewhere on the board
STRAIN_GAUGE9_AMPLIFIED: U22.4 (IN0); also elsewhere on the board
STRAIN_GAUGE10_AMPLIFIED: U22.5 (IN1); also elsewhere on the board
TT_CLK: U2.16 (CLK), U22.16 (CLK); also elsewhere on the board
TT_SDI: U2.15 (SDO), U22.15 (SDO); also elsewhere on the board
TT_SDO: U2.14 (SDI), U22.14 (SDI); also elsewhere on the board

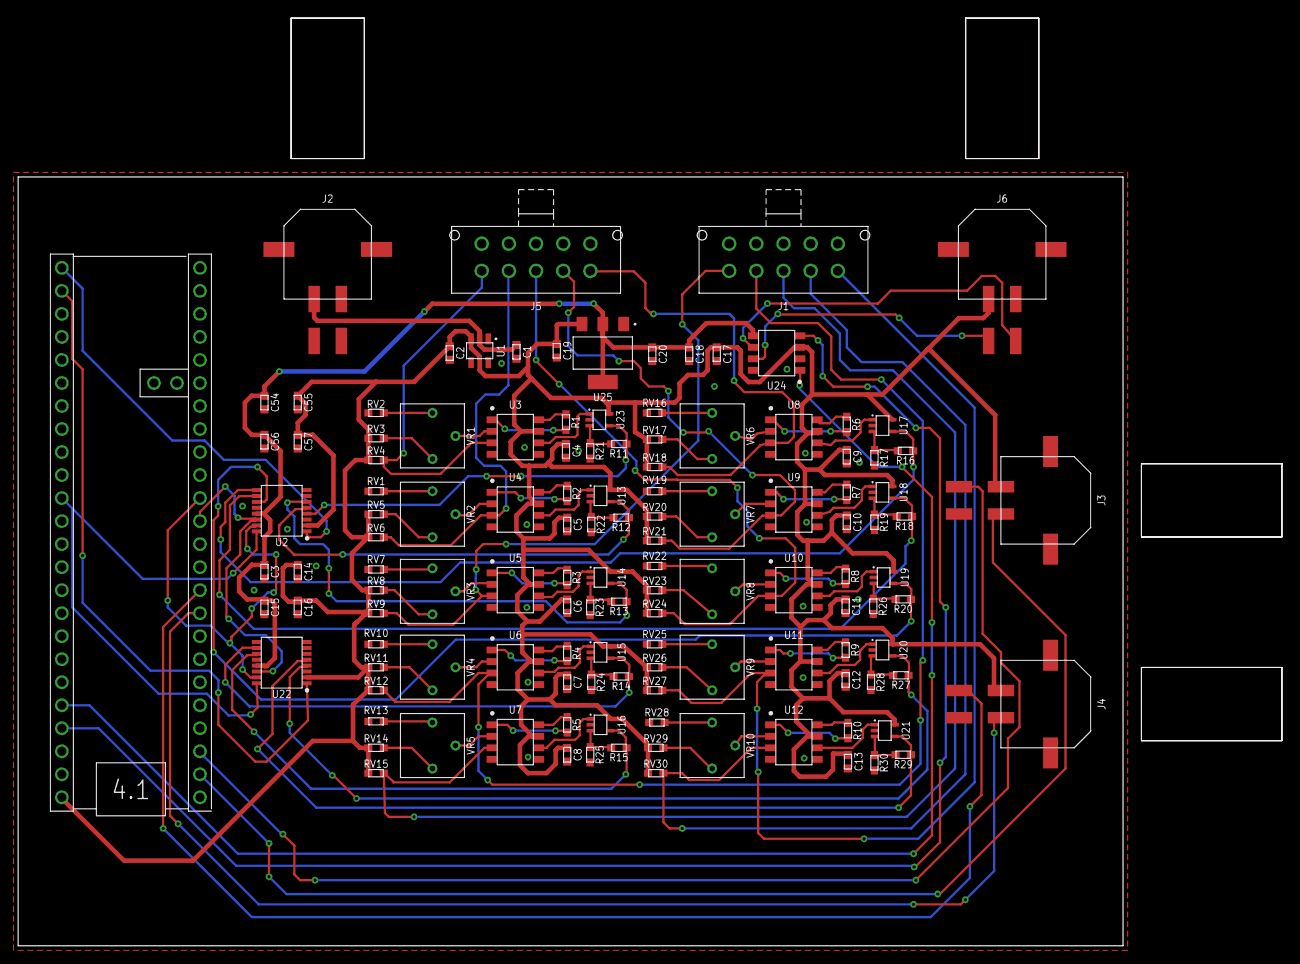
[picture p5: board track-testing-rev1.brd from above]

Board: 2 copper layers, 121.9 x 84.8 mm, 126 parts (0 on the bottom side), 108 nets.

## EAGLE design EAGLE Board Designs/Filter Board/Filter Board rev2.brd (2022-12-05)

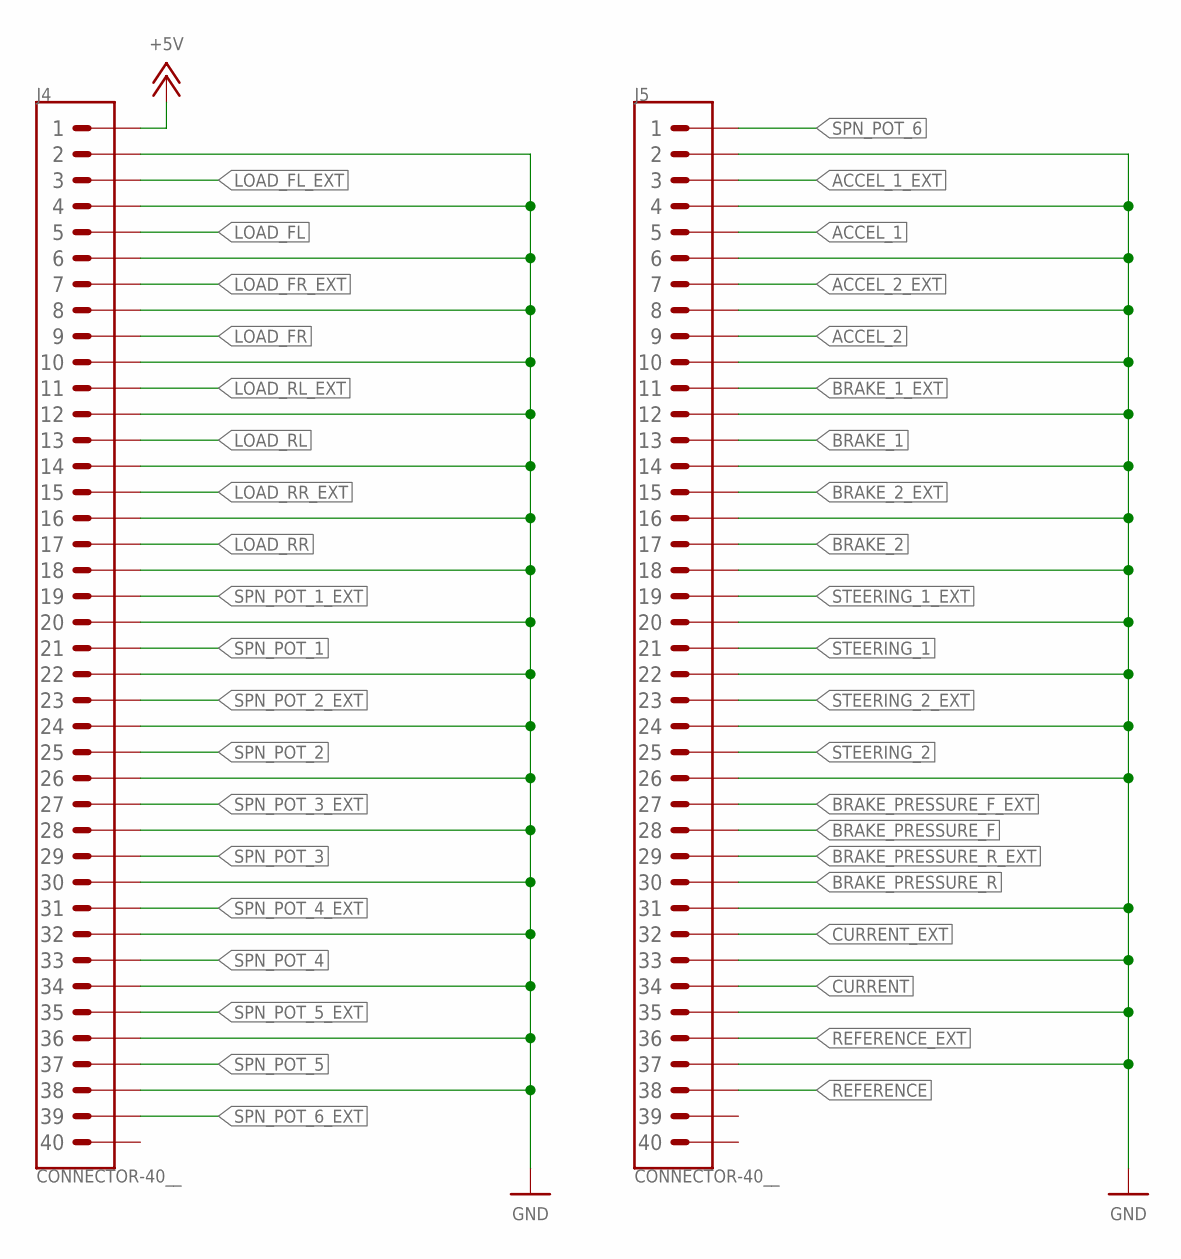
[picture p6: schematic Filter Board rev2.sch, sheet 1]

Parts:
J4, J5: CONNECTOR-40__; EHT-120-01

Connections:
+5V: J4.1; also elsewhere on the board
ACCEL_1: J5.5; also elsewhere on the board
ACCEL_1_EXT: J5.3; also elsewhere on the board
ACCEL_2: J5.9; also elsewhere on the board
ACCEL_2_EXT: J5.7; also elsewhere on the board
BRAKE_1: J5.13; also elsewhere on the board
BRAKE_1_EXT: J5.11; also elsewhere on the board
BRAKE_2: J5.17; also elsewhere on the board
BRAKE_2_EXT: J5.15; also elsewhere on the board
BRAKE_PRESSURE_F: J5.28; also elsewhere on the board
BRAKE_PRESSURE_F_EXT: J5.27; also elsewhere on the board
BRAKE_PRESSURE_R: J5.30; also elsewhere on the board
BRAKE_PRESSURE_R_EXT: J5.29; also elsewhere on the board
CURRENT: J5.34; also elsewhere on the board
CURRENT_EXT: J5.32; also elsewhere on the board
GND: J4.2, J4.4, J4.6, J4.8, J4.10, J4.12, J4.14, J4.16, J4.18, J4.20, J4.22, J4.24, J4.26, J4.28, J4.30, J4.32, J4.34, J4.36, J4.38, J5.2, J5.4, J5.6, J5.8, J5.10, J5.12, J5.14, J5.16, J5.18, J5.20, J5.22, J5.24, J5.26, J5.31, J5.33, J5.35, J5.37; also elsewhere on the board
LOAD_FL: J4.5; also elsewhere on the board
LOAD_FL_EXT: J4.3; also elsewhere on the board
LOAD_FR: J4.9; also elsewhere on the board
LOAD_FR_EXT: J4.7; also elsewhere on the board
LOAD_RL: J4.13; also elsewhere on the board
LOAD_RL_EXT: J4.11; also elsewhere on the board
LOAD_RR: J4.17; also elsewhere on the board
LOAD_RR_EXT: J4.15; also elsewhere on the board
REFERENCE: J5.38; also elsewhere on the board
REFERENCE_EXT: J5.36; also elsewhere on the board
SPN_POT_1: J4.21; also elsewhere on the board
SPN_POT_1_EXT: J4.19; also elsewhere on the board
SPN_POT_2: J4.25; also elsewhere on the board
SPN_POT_2_EXT: J4.23; also elsewhere on the board
SPN_POT_3: J4.29; also elsewhere on the board
SPN_POT_3_EXT: J4.27; also elsewhere on the board
SPN_POT_4: J4.33; also elsewhere on the board
SPN_POT_4_EXT: J4.31; also elsewhere on the board
SPN_POT_5: J4.37; also elsewhere on the board
SPN_POT_5_EXT: J4.35; also elsewhere on the board
SPN_POT_6: J5.1; also elsewhere on the board
SPN_POT_6_EXT: J4.39; also elsewhere on the board
STEERING_1: J5.21; also elsewhere on the board
STEERING_1_EXT: J5.19; also elsewhere on the board
STEERING_2: J5.25; also elsewhere on the board
STEERING_2_EXT: J5.23; also elsewhere on the board

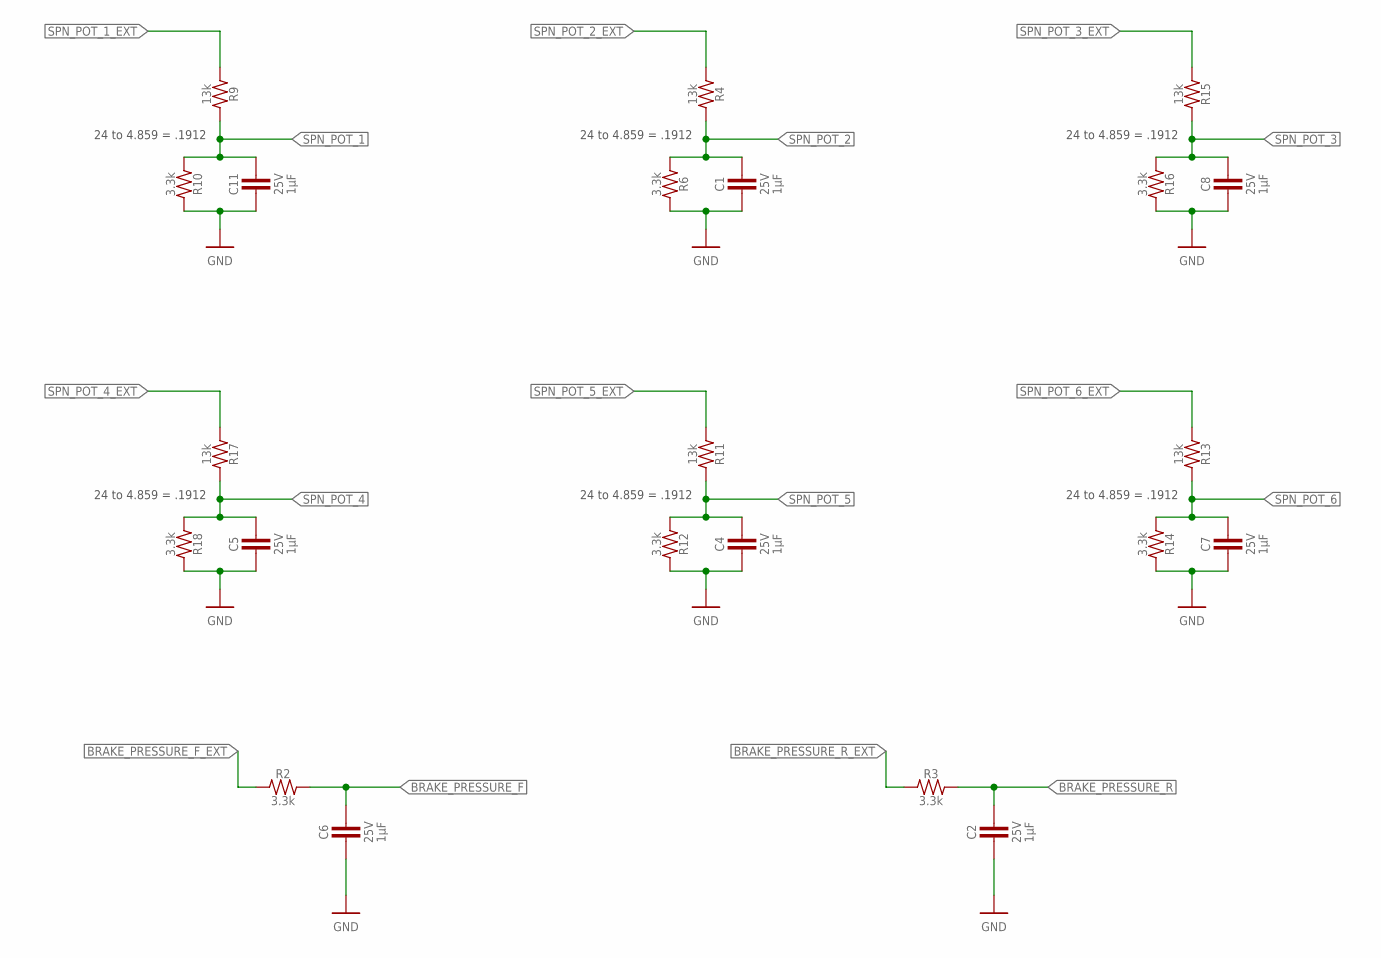
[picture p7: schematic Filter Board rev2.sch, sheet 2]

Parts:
C1, C2, C4, C5, C6, C7, C8, C11: CAPACITOR_0603_25V_1UF; 0603-CAP
R2, R3, R6, R10, R12, R14, R16, R18: RESISTOR_0603_3.3K; 0603-RES
R4, R9, R11, R13, R15, R17: RESISTOR_0603_13K; 0603-RES

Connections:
BRAKE_PRESSURE_F: C6.1, R2.2; also elsewhere on the board
BRAKE_PRESSURE_F_EXT: R2.1; also elsewhere on the board
BRAKE_PRESSURE_R: C2.1, R3.2; also elsewhere on the board
BRAKE_PRESSURE_R_EXT: R3.1; also elsewhere on the board
GND: C1.2, C2.2, C4.2, C5.2, C6.2, C7.2, C8.2, C11.2, R6.2, R10.2, R12.2, R14.2, R16.2, R18.2; also elsewhere on the board
SPN_POT_1: C11.1, R9.2, R10.1; also elsewhere on the board
SPN_POT_1_EXT: R9.1; also elsewhere on the board
SPN_POT_2: C1.1, R4.2, R6.1; also elsewhere on the board
SPN_POT_2_EXT: R4.1; also elsewhere on the board
SPN_POT_3: C8.1, R15.2, R16.1; also elsewhere on the board
SPN_POT_3_EXT: R15.1; also elsewhere on the board
SPN_POT_4: C5.1, R17.2, R18.1; also elsewhere on the board
SPN_POT_4_EXT: R17.1; also elsewhere on the board
SPN_POT_5: C4.1, R11.2, R12.1; also elsewhere on the board
SPN_POT_5_EXT: R11.1; also elsewhere on the board
SPN_POT_6: C7.1, R13.2, R14.1; also elsewhere on the board
SPN_POT_6_EXT: R13.1; also elsewhere on the board

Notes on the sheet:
24 to 4.859 = .1912

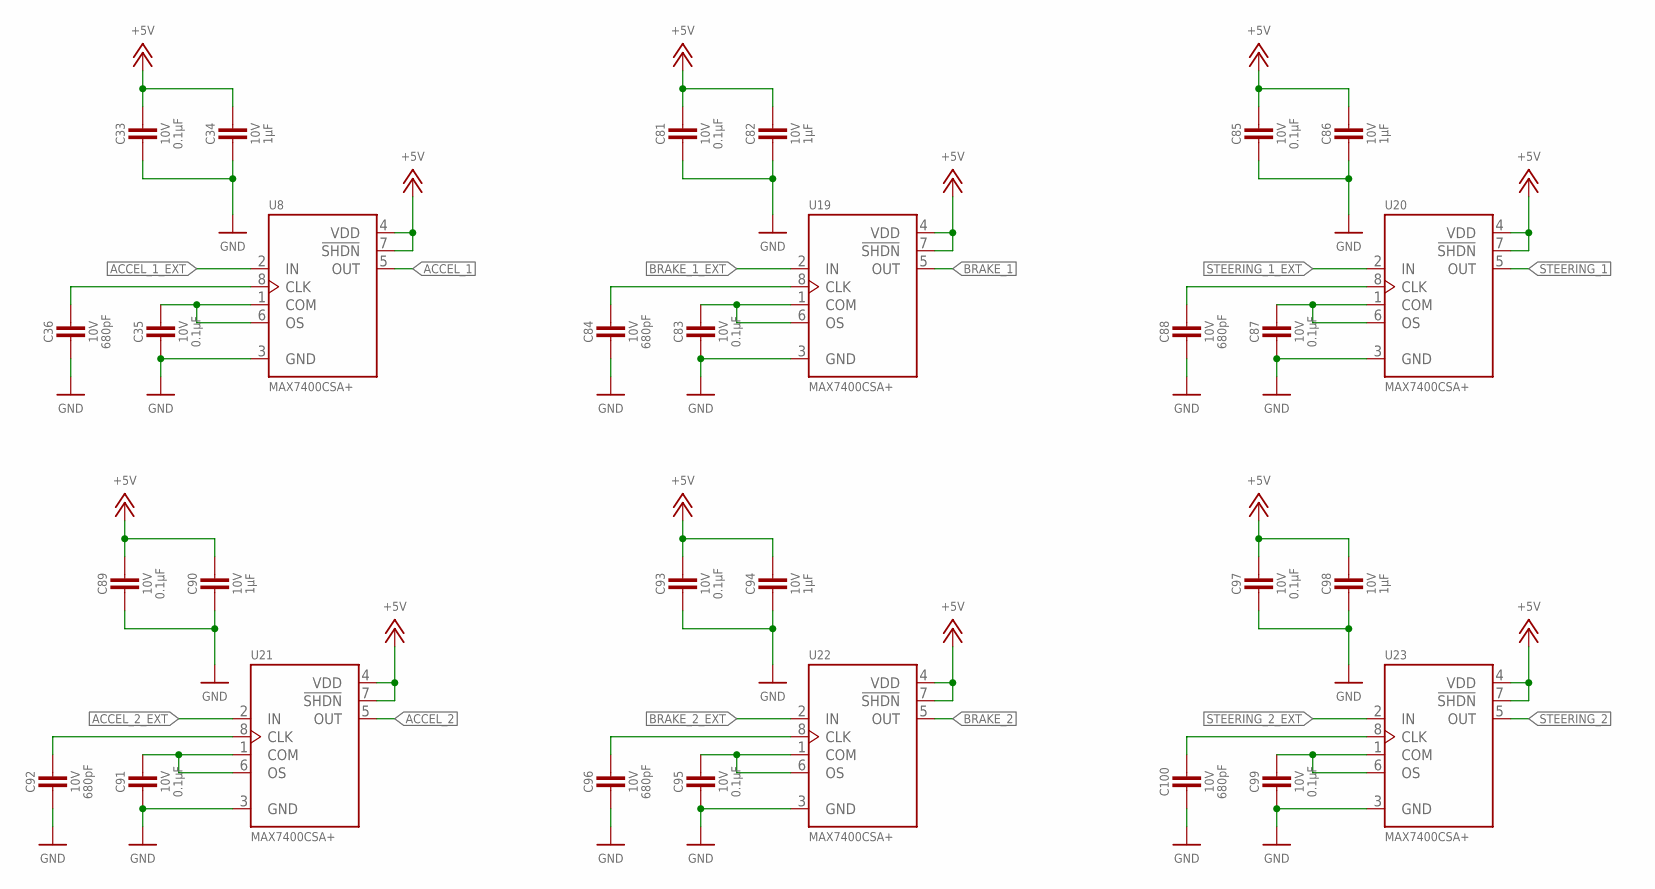
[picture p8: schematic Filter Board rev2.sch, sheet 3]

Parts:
C33, C35, C81, C83, C85, C87, C89, C91, C93, C95, C97, C99: CAPACITOR_0603_10V_0.1UF; 0603-CAP
C34, C82, C86, C90, C94, C98: CAPACITOR_0603_10V_1UF; 0603-CAP
C36, C84, C88, C92, C96, C100: CAPACITOR_0603_10V_680PF; 0603-CAP
U8, U19, U20, U21, U22, U23: MAX7400; SOIC-08(NARROW,0.15")

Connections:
+5V: C33.1, C34.1, C81.1, C82.1, C85.1, C86.1, C89.1, C90.1, C93.1, C94.1, C97.1, C98.1, U8.4 (VDD), U8.7 (!SHDN), U19.4 (VDD), U19.7 (!SHDN), U20.4 (VDD), U20.7 (!SHDN), U21.4 (VDD), U21.7 (!SHDN), U22.4 (VDD), U22.7 (!SHDN), U23.4 (VDD), U23.7 (!SHDN); also elsewhere on the board
ACCEL_1: U8.5 (OUT); also elsewhere on the board
ACCEL_1_EXT: U8.2 (IN); also elsewhere on the board
ACCEL_2: U21.5 (OUT); also elsewhere on the board
ACCEL_2_EXT: U21.2 (IN); also elsewhere on the board
BRAKE_1: U19.5 (OUT); also elsewhere on the board
BRAKE_1_EXT: U19.2 (IN); also elsewhere on the board
BRAKE_2: U22.5 (OUT); also elsewhere on the board
BRAKE_2_EXT: U22.2 (IN); also elsewhere on the board
GND: C33.2, C34.2, C35.2, C36.2, C81.2, C82.2, C83.2, C84.2, C85.2, C86.2, C87.2, C88.2, C89.2, C90.2, C91.2, C92.2, C93.2, C94.2, C95.2, C96.2, C97.2, C98.2, C99.2, C100.2, U8.3 (GND), U19.3 (GND), U20.3 (GND), U21.3 (GND), U22.3 (GND), U23.3 (GND); also elsewhere on the board
unnamed: C36.1, U8.8 (CLK)
unnamed: C35.1, U8.1 (COM), U8.6 (OS)
unnamed: C84.1, U19.8 (CLK)
unnamed: C83.1, U19.1 (COM), U19.6 (OS)
unnamed: C88.1, U20.8 (CLK)
unnamed: C87.1, U20.1 (COM), U20.6 (OS)
unnamed: C92.1, U21.8 (CLK)
unnamed: C91.1, U21.1 (COM), U21.6 (OS)
unnamed: C96.1, U22.8 (CLK)
unnamed: C95.1, U22.1 (COM), U22.6 (OS)
unnamed: C100.1, U23.8 (CLK)
unnamed: C99.1, U23.1 (COM), U23.6 (OS)
STEERING_1: U20.5 (OUT); also elsewhere on the board
STEERING_1_EXT: U20.2 (IN); also elsewhere on the board
STEERING_2: U23.5 (OUT); also elsewhere on the board
STEERING_2_EXT: U23.2 (IN); also elsewhere on the board

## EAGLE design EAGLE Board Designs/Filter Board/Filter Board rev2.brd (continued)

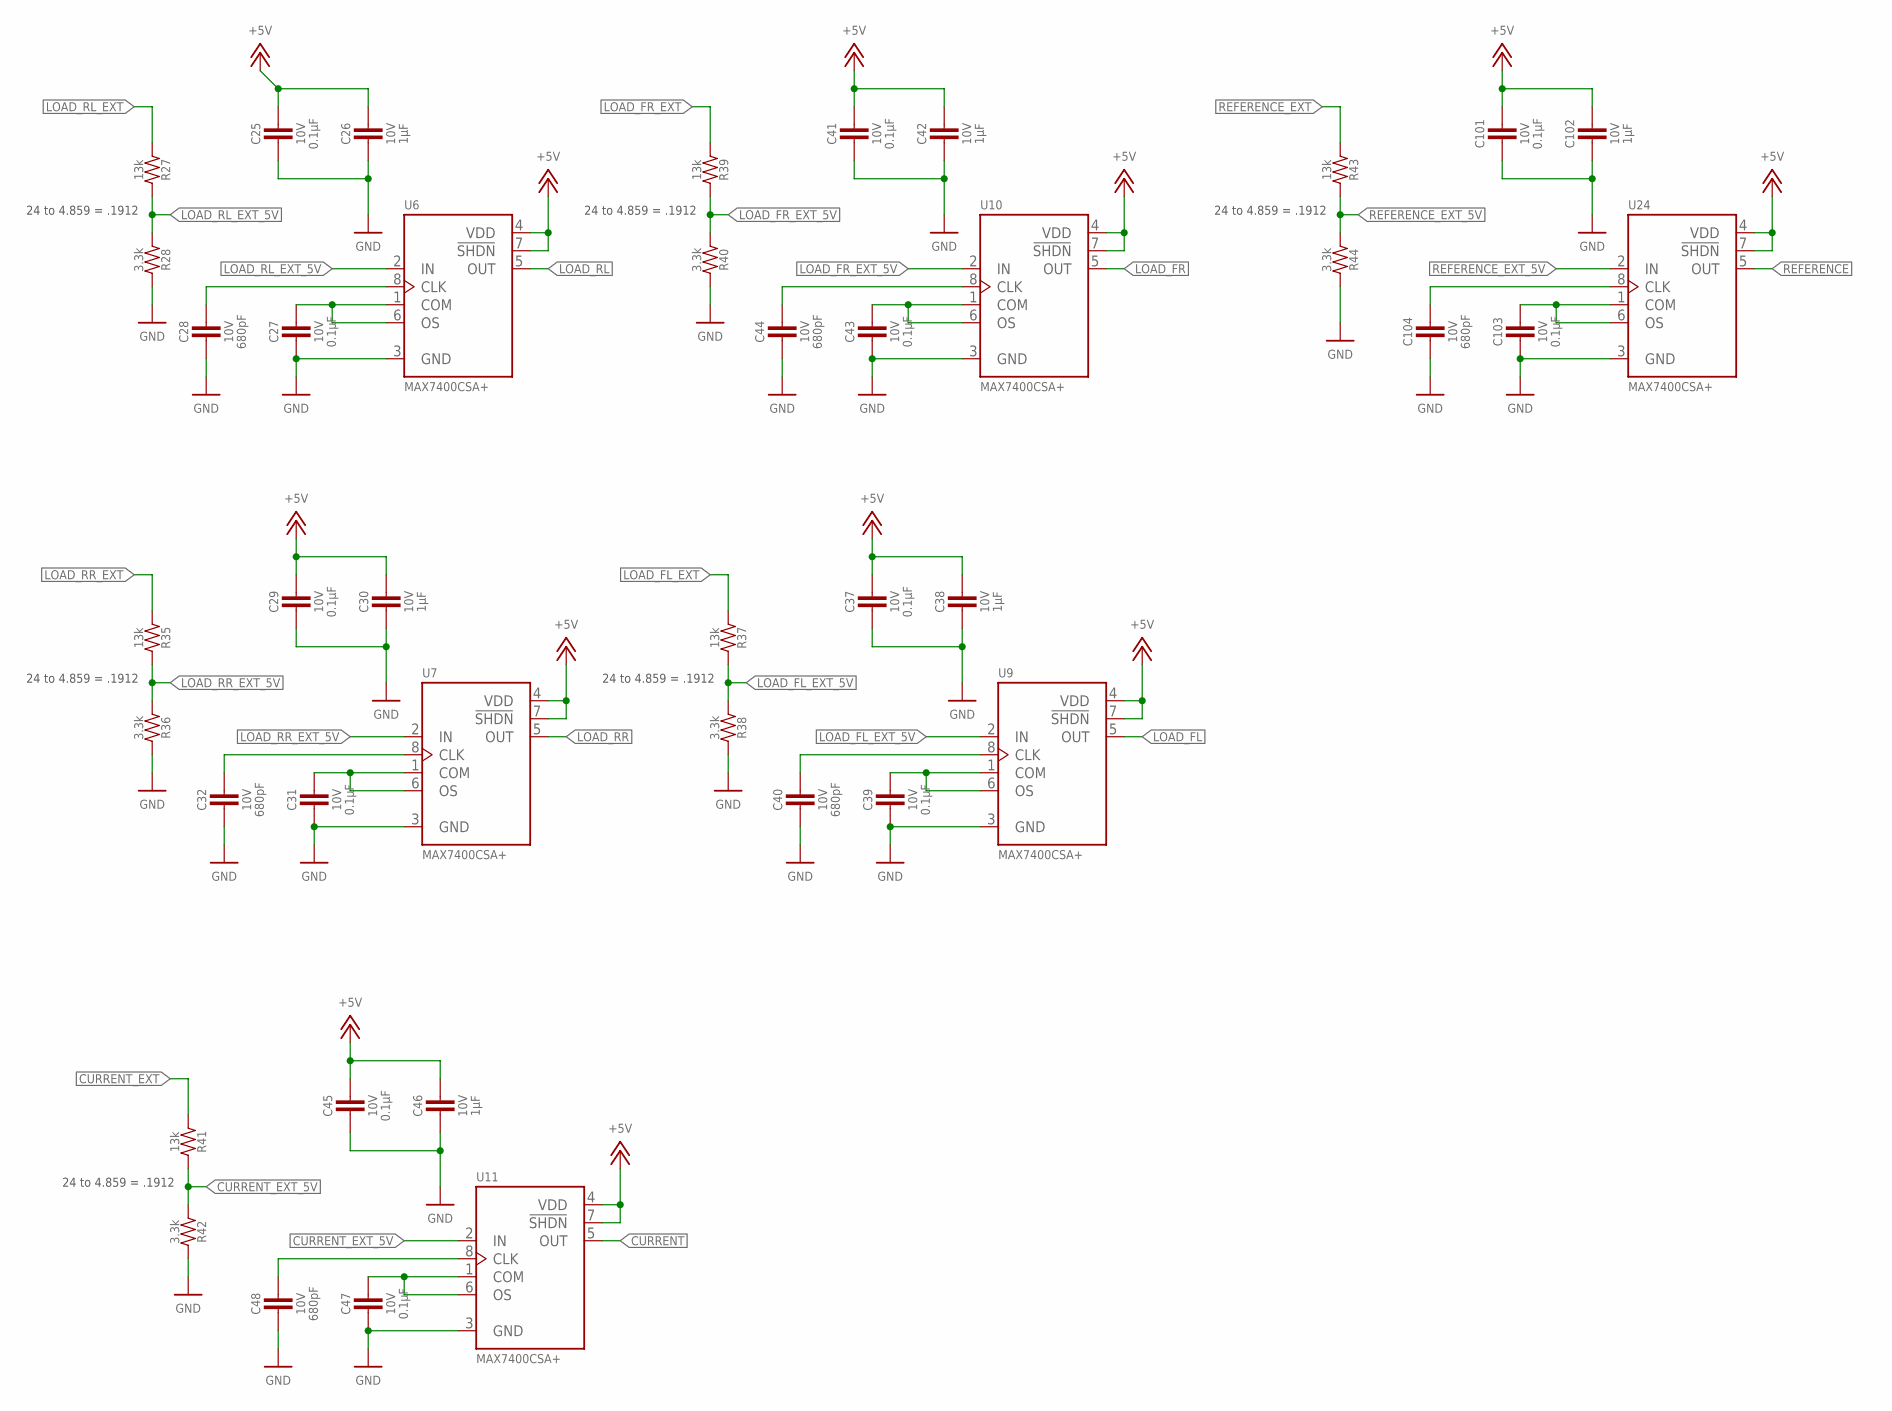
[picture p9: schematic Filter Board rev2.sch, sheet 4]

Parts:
C25, C27, C29, C31, C37, C39, C41, C43, C45, C47, C101, C103: CAPACITOR_0603_10V_0.1UF; 0603-CAP
C26, C30, C38, C42, C46, C102: CAPACITOR_0603_10V_1UF; 0603-CAP
C28, C32, C40, C44, C48, C104: CAPACITOR_0603_10V_680PF; 0603-CAP
R27, R35, R37, R39, R41, R43: RESISTOR_0603_13K; 0603-RES
R28, R36, R38, R40, R42, R44: RESISTOR_0603_3.3K; 0603-RES
U6, U7, U9, U10, U11, U24: MAX7400; SOIC-08(NARROW,0.15")

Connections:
+5V: C25.1, C26.1, C29.1, C30.1, C37.1, C38.1, C41.1, C42.1, C45.1, C46.1, C101.1, C102.1, U6.4 (VDD), U6.7 (!SHDN), U7.4 (VDD), U7.7 (!SHDN), U9.4 (VDD), U9.7 (!SHDN), U10.4 (VDD), U10.7 (!SHDN), U11.4 (VDD), U11.7 (!SHDN), U24.4 (VDD), U24.7 (!SHDN); also elsewhere on the board
CURRENT: U11.5 (OUT); also elsewhere on the board
CURRENT_EXT: R41.1; also elsewhere on the board
CURRENT_EXT_5V: R41.2, R42.1, U11.2 (IN)
GND: C25.2, C26.2, C27.2, C28.2, C29.2, C30.2, C31.2, C32.2, C37.2, C38.2, C39.2, C40.2, C41.2, C42.2, C43.2, C44.2, C45.2, C46.2, C47.2, C48.2, C101.2, C102.2, C103.2, C104.2, R28.2, R36.2, R38.2, R40.2, R42.2, R44.2, U6.3 (GND), U7.3 (GND), U9.3 (GND), U10.3 (GND), U11.3 (GND), U24.3 (GND); also elsewhere on the board
LOAD_FL: U9.5 (OUT); also elsewhere on the board
LOAD_FL_EXT: R37.1; also elsewhere on the board
LOAD_FL_EXT_5V: R37.2, R38.1, U9.2 (IN)
LOAD_FR: U10.5 (OUT); also elsewhere on the board
LOAD_FR_EXT: R39.1; also elsewhere on the board
LOAD_FR_EXT_5V: R39.2, R40.1, U10.2 (IN)
LOAD_RL: U6.5 (OUT); also elsewhere on the board
LOAD_RL_EXT: R27.1; also elsewhere on the board
LOAD_RL_EXT_5V: R27.2, R28.1, U6.2 (IN)
LOAD_RR: U7.5 (OUT); also elsewhere on the board
LOAD_RR_EXT: R35.1; also elsewhere on the board
LOAD_RR_EXT_5V: R35.2, R36.1, U7.2 (IN)
unnamed: C28.1, U6.8 (CLK)
unnamed: C27.1, U6.1 (COM), U6.6 (OS)
unnamed: C32.1, U7.8 (CLK)
unnamed: C31.1, U7.1 (COM), U7.6 (OS)
unnamed: C40.1, U9.8 (CLK)
unnamed: C39.1, U9.1 (COM), U9.6 (OS)
unnamed: C44.1, U10.8 (CLK)
unnamed: C43.1, U10.1 (COM), U10.6 (OS)
unnamed: C48.1, U11.8 (CLK)
unnamed: C47.1, U11.1 (COM), U11.6 (OS)
unnamed: C104.1, U24.8 (CLK)
unnamed: C103.1, U24.1 (COM), U24.6 (OS)
REFERENCE: U24.5 (OUT); also elsewhere on the board
REFERENCE_EXT: R43.1; also elsewhere on the board
REFERENCE_EXT_5V: R43.2, R44.1, U24.2 (IN)

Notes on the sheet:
24 to 4.859 = .1912

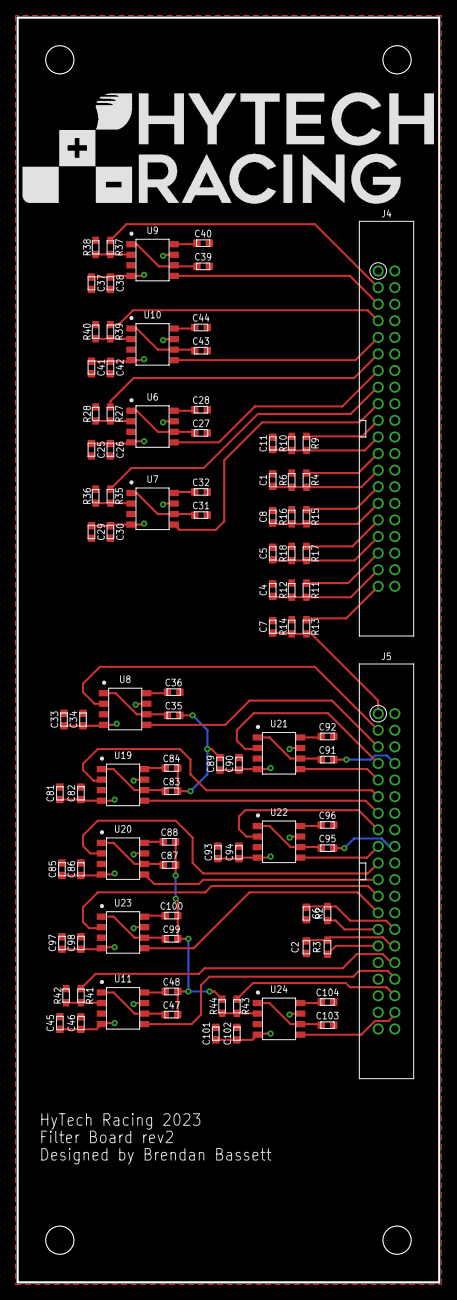
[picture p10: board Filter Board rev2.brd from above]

Board: 2 copper layers, 50.8 x 152.4 mm, 102 parts (1 on the bottom side), 72 nets.

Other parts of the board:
U$1, U$2, U$3, U$4: MOUNTING_M3
U$5, U$6: LOGO_HYTECH_LARGE

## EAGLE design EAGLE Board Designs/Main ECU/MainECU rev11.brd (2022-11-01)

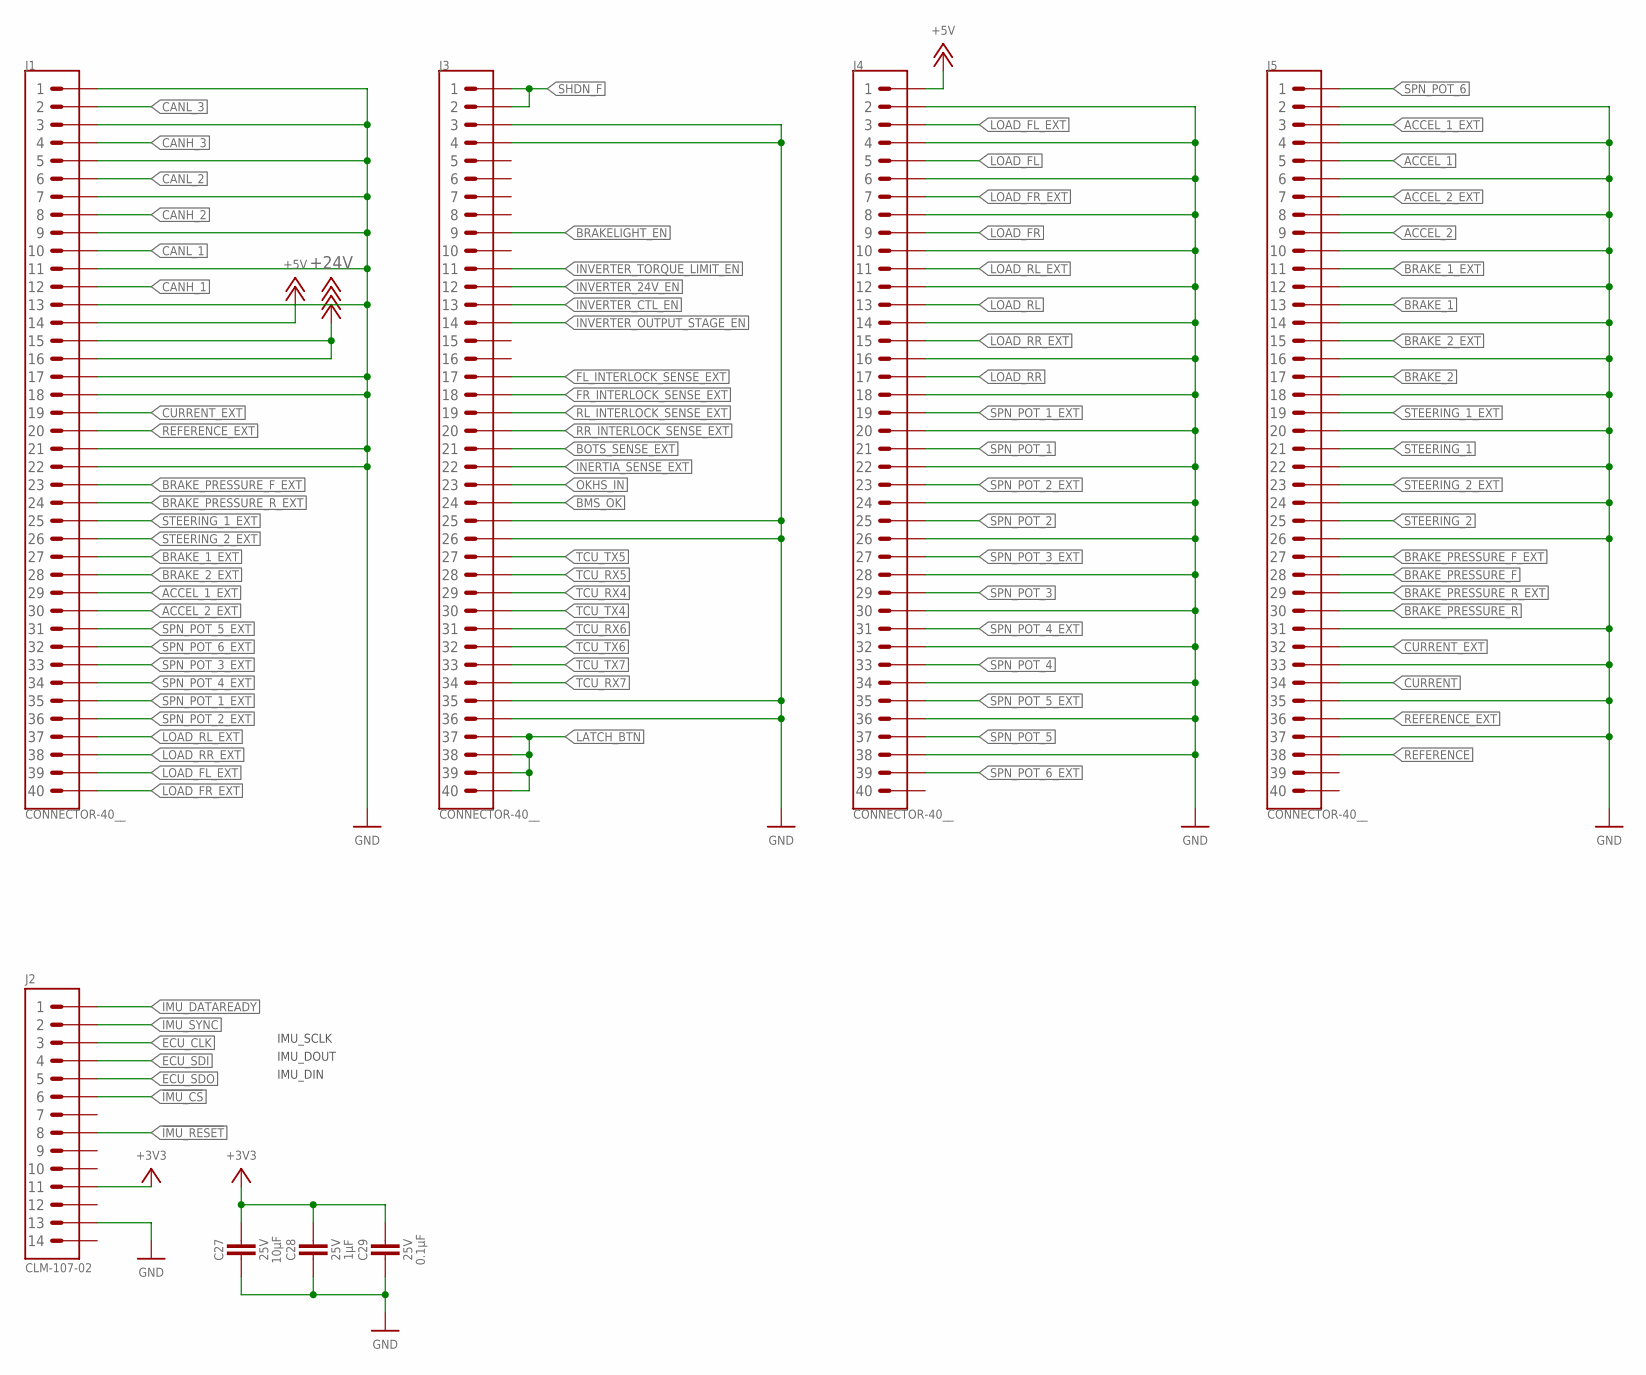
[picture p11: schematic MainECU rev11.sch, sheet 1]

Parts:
C27: CAPACITOR_0603_25V_10UF; 0603-CAP
C28: CAPACITOR_0603_25V_1UF; 0603-CAP
C29: CAPACITOR_0603_25V_0.1UF; 0603-CAP
J1, J3, J4, J5: CONNECTOR-40__; EHT-120-01
J2: ADIS16460

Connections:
!IMU_CS: J2.6; also elsewhere on the board
!IMU_RESET: J2.8; also elsewhere on the board
+3V3: C27.1, C28.1, C29.1, J2.11; also elsewhere on the board
+5V: J1.14, J4.1; also elsewhere on the board
+24V: J1.15, J1.16; also elsewhere on the board
ACCEL_1: J5.5; also elsewhere on the board
ACCEL_1_EXT: J1.29, J5.3
ACCEL_2: J5.9; also elsewhere on the board
ACCEL_2_EXT: J1.30, J5.7
BMS_OK: J3.24; also elsewhere on the board
BOTS_SENSE_EXT: J3.21; also elsewhere on the board
BRAKELIGHT_EN: J3.9; also elsewhere on the board
BRAKE_1: J5.13; also elsewhere on the board
BRAKE_1_EXT: J1.27, J5.11
BRAKE_2: J5.17; also elsewhere on the board
BRAKE_2_EXT: J1.28, J5.15
BRAKE_PRESSURE_F: J5.28; also elsewhere on the board
BRAKE_PRESSURE_F_EXT: J1.23, J5.27
BRAKE_PRESSURE_R: J5.30; also elsewhere on the board
BRAKE_PRESSURE_R_EXT: J1.24, J5.29
CANH_1: J1.12; also elsewhere on the board
CANH_2: J1.8; also elsewhere on the board
CANH_3: J1.4; also elsewhere on the board
CANL_1: J1.10; also elsewhere on the board
CANL_2: J1.6; also elsewhere on the board
CANL_3: J1.2; also elsewhere on the board
CURRENT: J5.34; also elsewhere on the board
CURRENT_EXT: J1.19, J5.32
ECU_CLK: J2.3; also elsewhere on the board
ECU_SDI: J2.4; also elsewhere on the board
ECU_SDO: J2.5; also elsewhere on the board
FL_INTERLOCK_SENSE_EXT: J3.17; also elsewhere on the board
FR_INTERLOCK_SENSE_EXT: J3.18; also elsewhere on the board
GND: C27.2, C28.2, C29.2, J1.1, J1.3, J1.5, J1.7, J1.9, J1.11, J1.13, J1.17, J1.18, J1.21, J1.22, J2.13, J3.3, J3.4, J3.25, J3.26, J3.35, J3.36, J4.2, J4.4, J4.6, J4.8, J4.10, J4.12, J4.14, J4.16, J4.18, J4.20, J4.22, J4.24, J4.26, J4.28, J4.30, J4.32, J4.34, J4.36, J4.38, J5.2, J5.4, J5.6, J5.8, J5.10, J5.12, J5.14, J5.16, J5.18, J5.20, J5.22, J5.24, J5.26, J5.31, J5.33, J5.35, J5.37; also elsewhere on the board
IMU_DATAREADY: J2.1; also elsewhere on the board
IMU_SYNC: J2.2; also elsewhere on the board
INERTIA_SENSE_EXT: J3.22; also elsewhere on the board
INVERTER_24V_EN: J3.12; also elsewhere on the board
INVERTER_CTL_EN: J3.13; also elsewhere on the board
INVERTER_OUTPUT_STAGE_EN: J3.14; also elsewhere on the board
INVERTER_TORQUE_LIMIT_EN: J3.11; also elsewhere on the board
LATCH_BTN: J3.37, J3.38, J3.39, J3.40; also elsewhere on the board
LOAD_FL: J4.5; also elsewhere on the board
LOAD_FL_EXT: J1.39, J4.3
LOAD_FR: J4.9; also elsewhere on the board
LOAD_FR_EXT: J1.40, J4.7
LOAD_RL: J4.13; also elsewhere on the board
LOAD_RL_EXT: J1.37, J4.11
LOAD_RR: J4.17; also elsewhere on the board
LOAD_RR_EXT: J1.38, J4.15
OKHS_IN: J3.23; also elsewhere on the board
REFERENCE: J5.38; also elsewhere on the board
REFERENCE_EXT: J1.20, J5.36
RL_INTERLOCK_SENSE_EXT: J3.19; also elsewhere on the board
RR_INTERLOCK_SENSE_EXT: J3.20; also elsewhere on the board
SHDN_F: J3.1, J3.2; also elsewhere on the board
SPN_POT_1: J4.21; also elsewhere on the board
SPN_POT_1_EXT: J1.35, J4.19
SPN_POT_2: J4.25; also elsewhere on the board
SPN_POT_2_EXT: J1.36, J4.23
SPN_POT_3: J4.29; also elsewhere on the board
SPN_POT_3_EXT: J1.33, J4.27
SPN_POT_4: J4.33; also elsewhere on the board
SPN_POT_4_EXT: J1.34, J4.31
SPN_POT_5: J4.37; also elsewhere on the board
SPN_POT_5_EXT: J1.31, J4.35
SPN_POT_6: J5.1; also elsewhere on the board
SPN_POT_6_EXT: J1.32, J4.39
STEERING_1: J5.21; also elsewhere on the board
STEERING_1_EXT: J1.25, J5.19
STEERING_2: J5.25; also elsewhere on the board
STEERING_2_EXT: J1.26, J5.23
TCU_RX4: J3.29; also elsewhere on the board
TCU_RX5: J3.28; also elsewhere on the board
TCU_RX6: J3.31; also elsewhere on the board
TCU_RX7: J3.34; also elsewhere on the board
TCU_TX4: J3.30; also elsewhere on the board
TCU_TX5: J3.27; also elsewhere on the board
TCU_TX6: J3.32; also elsewhere on the board
TCU_TX7: J3.33; also elsewhere on the board

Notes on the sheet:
IMU_DOUT
IMU_SCLK
IMU_DIN

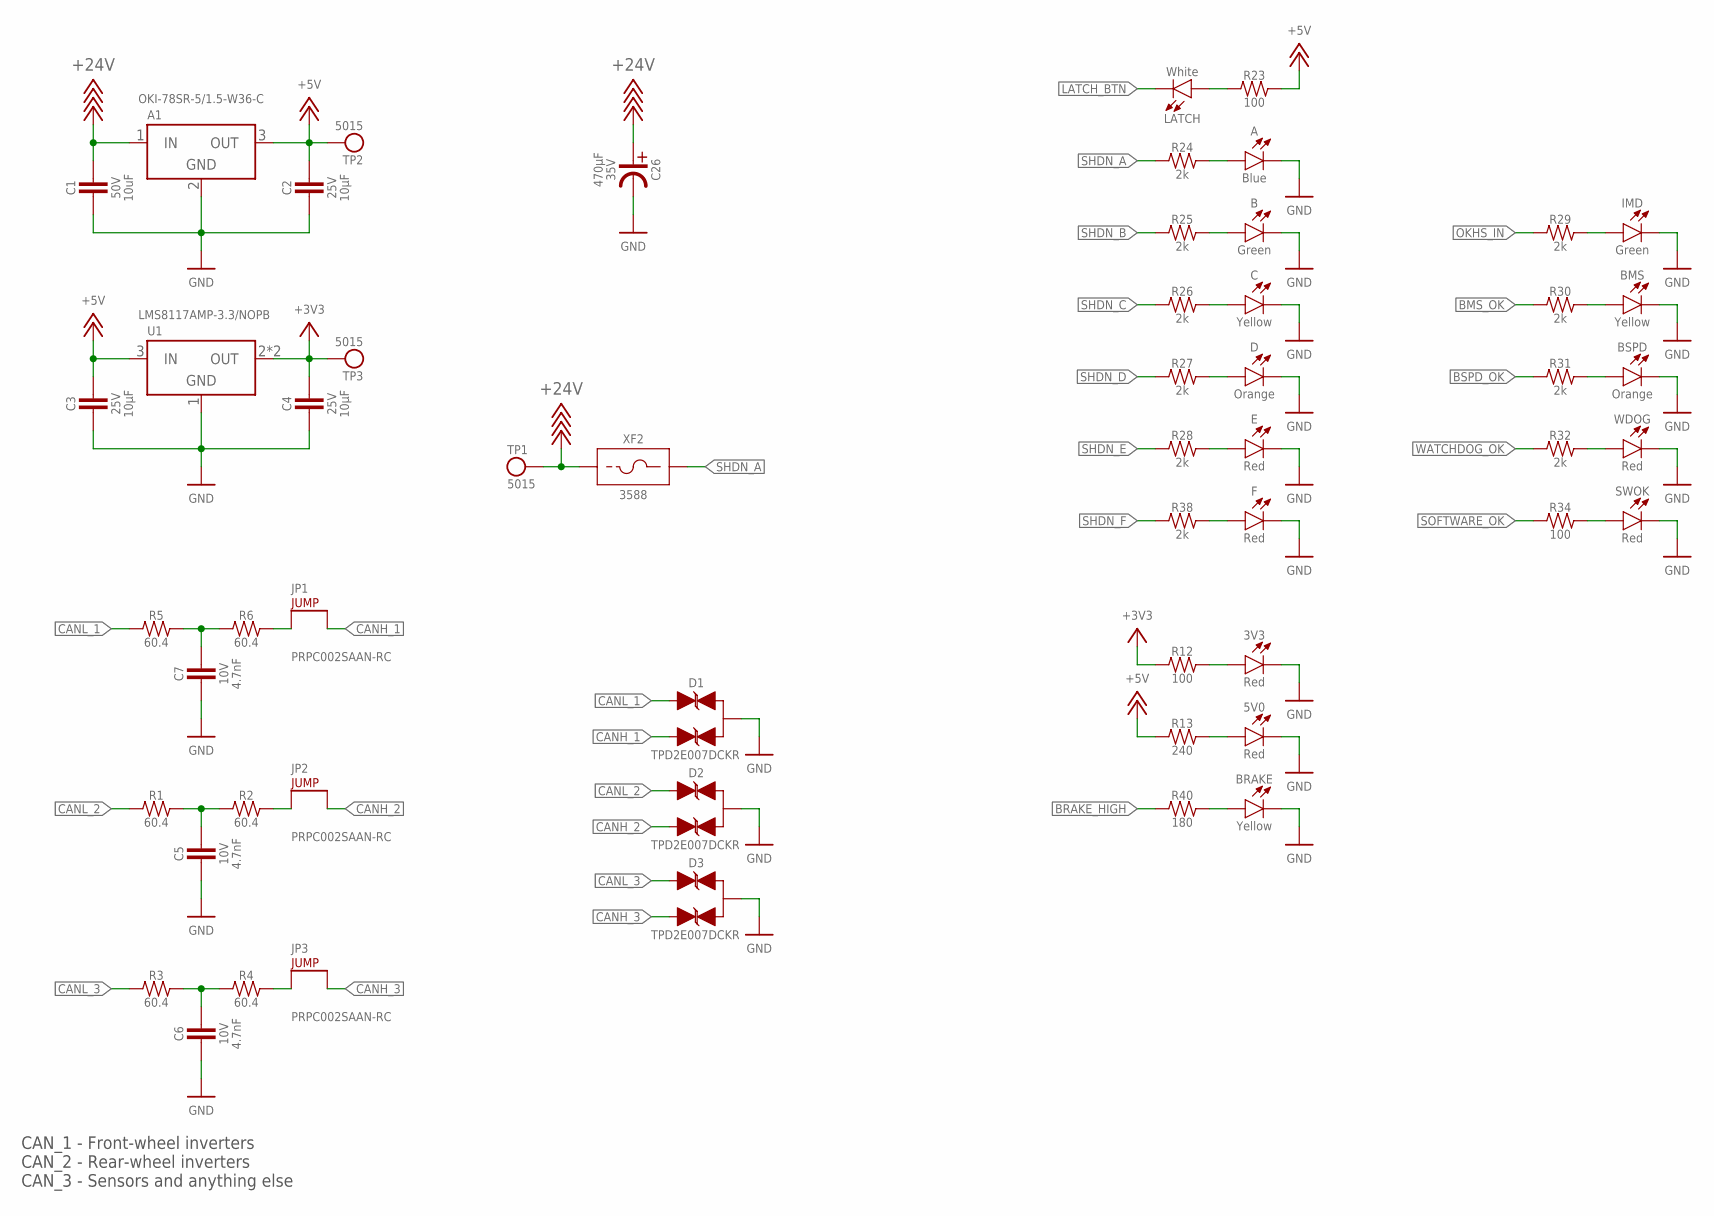
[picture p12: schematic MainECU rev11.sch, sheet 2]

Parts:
3V3, 5V0: LED_0603_RED; 0603-LED
A: LED_0603_BLUE; 0603-LED
A1: VOLTAGE_REGULATOR_MODULE_OKI-78SR_5V; OKI-78SR
B: LED_0603_GREEN; 0603-LED
BMS: LED_0603_YELLOW; 0603-LED
BRAKE: LED_0603_YELLOW; 0603-LED
BSPD: LED_0603_ORANGE; 0603-LED
C: LED_0603_YELLOW; 0603-LED
C1: CAPACITOR_0805_50V_10UF; 0805-CAP
C2, C3, C4: CAPACITOR_0603_25V_10UF; 0603-CAP
C5, C6, C7: CAPACITOR_0603_10V_4.7NF; 0603-CAP
C26: EEH-AZS1V471B; EEH-AZS
D: LED_0603_ORANGE; 0603-LED
D1, D2, D3: TVS_BIDIRECTIONAL_DUAL; SC-70-3
E: LED_0603_RED; 0603-LED
F: LED_0603_RED; 0603-LED
IMD: LED_0603_GREEN; 0603-LED
JP1, JP2, JP3: JUMPER__1X02; 1X02
LATCH: LED_0603_WHITE; 0603-LED
R1, R2, R3, R4, R5, R6: RESISTOR_0603_60.4; 0603-RES
R12, R23, R34: RESISTOR_0603_100; 0603-RES
R13: RESISTOR_0603_240; 0603-RES
R24, R25, R26, R27, R28, R29, R30, R31, R32, R38: RESISTOR_0603_2K; 0603-RES
R40: RESISTOR_0603_180; 0603-RES
SWOK: LED_0603_RED; 0603-LED
TP1, TP2, TP3: TEST_POINT; 5015
U1: VOLTAGE_REGULATOR_SOT-223_3.3V; SOT-223
WDOG: LED_0603_RED; 0603-LED
XF2: FUSE_HOLDER_MINIBLADESMD; 3588

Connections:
+3V3: C4.1, R12.1, TP3.1, U1.2 (OUT), U1.4 (OUT); also elsewhere on the board
+5V: A1.3 (OUT), C2.1, C3.1, R13.1, R23.2, TP2.1, U1.3 (IN); also elsewhere on the board
+24V: A1.1 (IN), C1.1, C26.PLUS, TP1.1, XF2.1, XF2.2 (1); also elsewhere on the board
BMS_OK: R30.1; also elsewhere on the board
BRAKE_HIGH: R40.1; also elsewhere on the board
BSPD_OK: R31.1; also elsewhere on the board
CANH_1: D1.2 (C2), JP1.2; also elsewhere on the board
CANH_2: D2.2 (C2), JP2.2; also elsewhere on the board
CANH_3: D3.2 (C2), JP3.2; also elsewhere on the board
CANL_1: D1.1 (C1), R5.1; also elsewhere on the board
CANL_2: D2.1 (C1), R1.1; also elsewhere on the board
CANL_3: D3.1 (C1), R3.1; also elsewhere on the board
GND: 3V3.1 (C), 5V0.1 (C), A.1 (C), A1.2 (GND), B.1 (C), BMS.1 (C), BRAKE.1 (C), BSPD.1 (C), C.1 (C), C1.2, C2.2, C3.2, C4.2, C5.2, C6.2, C7.2, C26.MINUS, D.1 (C), D1.3 (A), D2.3 (A), D3.3 (A), E.1 (C), F.1 (C), IMD.1 (C), SWOK.1 (C), U1.1 (GND), WDOG.1 (C); also elsewhere on the board
LATCH_BTN: LATCH.1 (C); also elsewhere on the board
unnamed: JP1.1, R6.2
unnamed: JP2.1, R2.2
unnamed: JP3.1, R4.2
unnamed: C5.1, R1.2, R2.1
unnamed: C6.1, R3.2, R4.1
unnamed: C7.1, R5.2, R6.1
unnamed: F.2 (A), R38.2
unnamed: LATCH.2 (A), R23.1
unnamed: A.2 (A), R24.2
unnamed: B.2 (A), R25.2
unnamed: C.2 (A), R26.2
unnamed: D.2 (A), R27.2
unnamed: E.2 (A), R28.2
unnamed: IMD.2 (A), R29.2
unnamed: BMS.2 (A), R30.2
unnamed: BSPD.2 (A), R31.2
unnamed: R32.2, WDOG.2 (A)
unnamed: 3V3.2 (A), R12.2
unnamed: R34.2, SWOK.2 (A)
unnamed: 5V0.2 (A), R13.2
unnamed: BRAKE.2 (A), R40.2
OKHS_IN: R29.1; also elsewhere on the board
SHDN_A: R24.1, XF2.3 (2), XF2.4 (2); also elsewhere on the board
SHDN_B: R25.1; also elsewhere on the board
SHDN_C: R26.1; also elsewhere on the board
SHDN_D: R27.1; also elsewhere on the board
SHDN_E: R28.1; also elsewhere on the board
SHDN_F: R38.1; also elsewhere on the board
SOFTWARE_OK: R34.1; also elsewhere on the board
WATCHDOG_OK: R32.1; also elsewhere on the board

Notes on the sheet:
CAN_1 - Front-wheel inverters CAN_2 - Rear-wheel inverters CAN_3 - Sensors and anything else


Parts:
C92, C93, C95, C99, C101: CAPACITOR_0603_10V_0.1UF; 0603-CAP
D37, D38: TVS_15V; SOT-23
Q3: TRANSISTOR_P_MOS_SOT-23_DMP3056L-7; SOT-23
Q4: TRANSISTOR_N_MOS__DMG3406L-7; SOT-23
R58: RESISTOR_0603_1K; 0603-RES
R59: RESISTOR_0603_41.2K; 0603-RES
R60, R61, R65: RESISTOR_0603_10K; 0603-RES
R62, R68: RESISTOR_0603_10.2K; 0603-RES
R63, R69: RESISTOR_0603_1.13K; 0603-RES
R64, R66: RESISTOR_0603_5.1K; 0603-RES
TP4, TP5, TP6: TEST_POINT; 5015
U34, U37, U39, U41, U43: OPAMP_1_CHANNEL_OPA991; SC-70-5
U38: LOGICGATE_OR; SC-70-5
U42: LOGICGATE_AND_DCK3; SC-70-5
U44: LOGICGATE_NOR; SC-70-5
VR1: RESISTOR_TRIMPOT_10K_3362P; 3362P

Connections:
+5V: C92.1, C93.1, C95.1, C99.1, C101.1, R60.2, R62.2, R68.2, U34.5 (VDD), U37.5 (VDD), U38.5 (VDD), U39.5 (VDD), U41.5 (VDD), U42.5 (VDD), U43.5 (VDD), U44.5 (VDD), VR1.3 (2); also elsewhere on the board
+24V: D37.3 (C), Q3.2 (S), R64.2; also elsewhere on the board
BRAKE_1: U41.1 (VIN+), U43.1 (VIN+); also elsewhere on the board
BRAKE_HIGH: U41.4 (VOUT), U42.1 (IN1); also elsewhere on the board
BRAKE_MISSING: TP6.1, U38.1 (IN1), U43.4 (VOUT)
BSPD_FAULT: U42.4 (OUT), U44.2 (IN2)
BSPD_OK: Q3.3 (D); also elsewhere on the board
BSPD_OK_LV: D38.3 (C), Q4.1 (G), R65.2, U44.4 (OUT)
CURRENT: U34.1 (VIN+), U39.1 (VIN+); also elsewhere on the board
CURRENT_HIGH: TP5.1, U37.4 (VOUT), U42.2 (IN2)
CURRENT_MISSING: TP4.1, U38.2 (IN2), U39.4 (VOUT)
GND: C92.2, C93.2, C95.2, C99.2, C101.2, D38.1 (A), Q4.2 (S), R61.1, R63.1, R65.1, R69.1, U34.2 (GND), U37.2 (GND), U38.3 (GND), U39.2 (GND), U41.2 (GND), U42.3 (GND), U43.2 (GND), U44.3 (GND), VR1.1; also elsewhere on the board
unnamed: R60.1, R61.2, U37.3 (VIN-)
unnamed: R58.2, R59.1, U34.3 (VIN-)
unnamed: R59.2, U34.4 (VOUT), U37.1 (VIN+)
unnamed: R62.1, R63.2, U39.3 (VIN-)
unnamed: U41.3 (VIN-), VR1.2 (3)
unnamed: D37.1 (A), Q3.1 (G), R64.1, R66.2
unnamed: Q4.3 (D), R66.1
unnamed: R68.1, R69.2, U43.3 (VIN-)
REFERENCE: R58.1; also elsewhere on the board
SIG_MISSING: U38.4 (OUT), U44.1 (IN1)

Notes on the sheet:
Current sensor is ISB-300-A-802 6.667mV/A ACU amp gain is 4.832x Decimation divider is 0.203x Final current slope is 6.540mV/A 5kW at 530V is 9.434A Signal will be 61.698mV above reference Non-inverting op-amp with 1k and 41.2k has 42.2x gain. Boosts 5kW signal to 2.603V. Comparing to 2.5V referenc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
BRAKE_1 needs to be positive coefficient signal (increasing brake request = inrcreasing voltage)


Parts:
D4, D5, D6, D7, D24, D25, D29, D30, D31, D32, D33, D34, D35, D40, D41, D42, D43, D44, D45, D46: SCHOTTKY_SOD323_30V; SOD-323
D36, D39: TVS_15V; SOT-23
K1, K9, K10, K11, K12: RELAY_DPDT_RT424024; RT*2*
Q5: TRANSISTOR_P_MOS_SOT-23_DMP3056L-7; SOT-23
Q6: TRANSISTOR_N_MOS__DMG3406L-7; SOT-23
R7, R10, R15, R17, R19, R21, R33, R44, R46, R48, R50, R52: RESISTOR_0603_10K; 0603-RES
R8, R9: RESISTOR_0603_5.1K; 0603-RES
R11, R16, R18, R20, R22, R45, R47, R49, R51, R53: RESISTOR_0603_1.33K; 0603-RES
U5: ADM8316WBX30; SOT-23-5

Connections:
+3V3: U5.5 (VDD); also elsewhere on the board
+24V: D36.3 (C), Q5.2 (S), R9.2; also elsewhere on the board
BMS_OK: D6.C, K10.A1 (COIL+); also elsewhere on the board
BOTS_SENSE: R19.1, R20.2; also elsewhere on the board
BOTS_SENSE_EXT: D43.A, D45.C, K1.A1 (COIL+); also elsewhere on the board
BSPD_OK: D24.C, K11.A1 (COIL+); also elsewhere on the board
FL_INTERLOCK_SENSE: R44.1, R45.2; also elsewhere on the board
FL_INTERLOCK_SENSE_EXT: D29.A; also elsewhere on the board
FR_INTERLOCK_SENSE: R10.1, R11.2; also elsewhere on the board
FR_INTERLOCK_SENSE_EXT: D40.A; also elsewhere on the board
GND: D39.1 (A), K1.14 (4), K9.14 (4), K10.14 (4), K11.14 (4), K12.14 (4), Q6.2 (S), R7.1, R11.1, R16.1, R18.1, R20.1, R22.1, R33.1, R45.1, R47.1, R49.1, R51.1, R53.1, U5.2 (GND); also elsewhere on the board
INERTIA_SENSE: R21.1, R22.2; also elsewhere on the board
INERTIA_SENSE_EXT: D44.A; also elsewhere on the board
LATCH_BTN: D5.C, D7.C, D25.C, D35.C, D46.C; also elsewhere on the board
unnamed: D40.C, R10.2
unnamed: D36.1 (A), Q5.1 (G), R8.2, R9.1
unnamed: Q6.3 (D), R8.1
unnamed: D41.C, R15.2
unnamed: D42.C, R17.2
unnamed: D43.C, R19.2
unnamed: D44.C, R21.2
unnamed: D4.A, D5.A, K9.11 (3), K9.A2 (COIL-)
unnamed: D24.A, D25.A, K11.11 (3), K11.A2 (COIL-)
unnamed: D6.A, D7.A, K10.11 (3), K10.A2 (COIL-)
unnamed: D45.A, D46.A, K1.11 (3), K1.A2 (COIL-)
unnamed: D34.A, D35.A, K12.11 (3), K12.A2 (COIL-)
unnamed: D29.C, R44.2
unnamed: D30.C, R46.2
unnamed: D31.C, R48.2
unnamed: D32.C, R50.2
unnamed: D33.C, R52.2
OKHS_IN: D4.C, K9.A1 (COIL+); also elsewhere on the board
RL_INTERLOCK_SENSE: R15.1, R16.2; also elsewhere on the board
RL_INTERLOCK_SENSE_EXT: D41.A; also elsewhere on the board
RR_INTERLOCK_SENSE: R17.1, R18.2; also elsewhere on the board
RR_INTERLOCK_SENSE_EXT: D42.A; also elsewhere on the board
SHDN_A: K9.21 (6); also elsewhere on the board
SHDN_B: D30.A, K9.24 (5), K10.21 (6); also elsewhere on the board
SHDN_B_READ: R46.1, R47.2; also elsewhere on the board
SHDN_C: D31.A, K10.24 (5), K11.21 (6); also elsewhere on the board
SHDN_C_READ: R48.1, R49.2; also elsewhere on the board
SHDN_D: D32.A, K11.24 (5), K12.21 (6); also elsewhere on the board
SHDN_D_READ: R50.1, R51.2; also elsewhere on the board
SHDN_E: D33.A, K1.21 (6), K12.24 (5); also elsewhere on the board
SHDN_E_READ: R52.1, R53.2; also elsewhere on the board
SHDN_F: K1.24 (5); also elsewhere on the board
SOFTWARE_OK: R33.2, U5.3 (!MR!); also elsewhere on the board
WATCHDOG: U5.4 (WDI); also elsewhere on the board
WATCHDOG_OK: D34.C, K12.A1 (COIL+), Q5.3 (D); also elsewhere on the board
WATCHDOG_OK_LV: D39.3 (C), Q6.1 (G), R7.2, U5.1 (!RESET!)

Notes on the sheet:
to BOTS
24V -> 2.834V divider

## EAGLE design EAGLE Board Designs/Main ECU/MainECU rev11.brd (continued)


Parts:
A2: TEENSY_4.1; TEENSY_LONG_EXT
C8, C12, C13, C14, C15, C16, C17, C18, C19, C20, C23, C54, C55: CAPACITOR_0603_10V_0.1UF; 0603-CAP
C10, C21, C22, C24, C25, C56, C57: CAPACITOR_0603_10V_1UF; 0603-CAP
U2, U3, U4: TCAN1051HQV-Q1; SOIC-08(NARROW,0.15")
U6, U7, U23: ADC128S022; TSSOP-16

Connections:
3.3V: A2.3V3 (3.3V), A2.3V3@2 (3.3V), A2.3V3@3 (3.3V); also elsewhere on the board
!AD1_CS: A2.D41 (A17), U23.1 (!CS!)
!AD2_CS: A2.D40 (A16), U7.1 (!CS!)
!AD3_CS: A2.D39 (A15), U6.1 (!CS!)
!IMU_CS: A2.D3; also elsewhere on the board
!IMU_RESET: A2.D2; also elsewhere on the board
+3V3: C13.1, C15.1, C17.1, C18.1, C19.1, C21.1, C24.1, C54.1, C56.1, U2.5 (VIO), U3.5 (VIO), U4.5 (VIO), U6.13 (VLOGIC), U7.13 (VLOGIC), U23.13 (VLOGIC); also elsewhere on the board
+5V: A2.VIN, C8.1, C10.1, C12.1, C14.1, C16.1, C20.1, C22.1, C23.1, C25.1, C55.1, C57.1, U2.3 (VDD), U3.3 (VDD), U4.3 (VDD), U6.2 (AVDD), U7.2 (AVDD), U23.2 (AVDD); also elsewhere on the board
ACCEL_1: U7.6 (IN2); also elsewhere on the board
ACCEL_2: U7.7 (IN3); also elsewhere on the board
BOTS_SENSE: A2.D29; also elsewhere on the board
BRAKELIGHT_EN: A2.D6; also elsewhere on the board
BRAKE_1: U7.8 (IN4); also elsewhere on the board
BRAKE_2: U7.11 (IN7); also elsewhere on the board
BRAKE_PRESSURE_F: U6.4 (IN0); also elsewhere on the board
BRAKE_PRESSURE_R: U6.5 (IN1); also elsewhere on the board
CANH_1: U2.7 (CANH); also elsewhere on the board
CANH_2: U3.7 (CANH); also elsewhere on the board
CANH_3: U4.7 (CANH); also elsewhere on the board
CANL_1: U2.6 (CANL); also elsewhere on the board
CANL_2: U3.6 (CANL); also elsewhere on the board
CANL_3: U4.6 (CANL); also elsewhere on the board
CAN_ECU_RX1: A2.D22 (A8), U2.4 (RXD)
CAN_ECU_RX2: A2.D0 ((CRX1)D0), U3.4 (RXD)
CAN_ECU_RX3: A2.D30, U4.4 (RXD)
CAN_ECU_TX1: A2.D23 (A9), U2.1 (TXD)
CAN_ECU_TX2: A2.D1 ((CTX1)D1), U3.1 (TXD)
CAN_ECU_TX3: A2.D31, U4.1 (TXD)
CURRENT: U6.6 (IN2); also elsewhere on the board
ECU_CLK: A2.D13 ((CLK)D13), U6.16 (CLK), U7.16 (CLK), U23.16 (CLK); also elsewhere on the board
ECU_SDI: A2.D12 ((SDI)D12), U6.15 (SDO), U7.15 (SDO), U23.15 (SDO); also elsewhere on the board
ECU_SDO: A2.D11 ((SDO)D11), U6.14 (SDI), U7.14 (SDI), U23.14 (SDI); also elsewhere on the board
FL_INTERLOCK_SENSE: A2.D25 (A11); also elsewhere on the board
FR_INTERLOCK_SENSE: A2.D24 (A10); also elsewhere on the board
GND: A2.AGND/GND (GND), A2.GND, A2.GND@2 (GND), C8.2, C10.2, C12.2, C13.2, C14.2, C15.2, C16.2, C17.2, C18.2, C19.2, C20.2, C21.2, C22.2, C23.2, C24.2, C25.2, C54.2, C55.2, C56.2, C57.2, U2.2 (GND), U3.2 (GND), U4.2 (GND), U6.3 (AGND), U6.12 (GND), U7.3 (AGND), U7.12 (GND), U23.3 (AGND), U23.12 (GND); also elsewhere on the board
IMU_DATAREADY: A2.D5; also elsewhere on the board
IMU_SYNC: A2.D4; also elsewhere on the board
INERTIA_SENSE: A2.D28; also elsewhere on the board
INVERTER_24V_EN: A2.D7; also elsewhere on the board
INVERTER_CTL_EN: A2.D10 ((CS)D10); also elsewhere on the board
INVERTER_OUTPUT_STAGE_EN: A2.D9; also elsewhere on the board
INVERTER_TORQUE_LIMIT_EN: A2.D8; also elsewhere on the board
LOAD_FL: U23.4 (IN0); also elsewhere on the board
LOAD_FR: U23.5 (IN1); also elsewhere on the board
LOAD_RL: U23.6 (IN2); also elsewhere on the board
LOAD_RR: U23.7 (IN3); also elsewhere on the board
REFERENCE: U6.7 (IN3); also elsewhere on the board
RL_INTERLOCK_SENSE: A2.D27 (A13); also elsewhere on the board
RR_INTERLOCK_SENSE: A2.D26 (A12); also elsewhere on the board
SHDN_B_READ: A2.D33; also elsewhere on the board
SHDN_C_READ: A2.D34; also elsewhere on the board
SHDN_D_READ: A2.D35; also elsewhere on the board
SHDN_E_READ: A2.D36; also elsewhere on the board
SOFTWARE_OK: A2.D20 (A6); also elsewhere on the board
SPN_POT_1: U23.8 (IN4); also elsewhere on the board
SPN_POT_2: U23.11 (IN7); also elsewhere on the board
SPN_POT_3: U23.10 (IN6); also elsewhere on the board
SPN_POT_4: U23.9 (IN5); also elsewhere on the board
SPN_POT_5: U7.4 (IN0); also elsewhere on the board
SPN_POT_6: U7.5 (IN1); also elsewhere on the board
STEERING_1: U7.10 (IN6); also elsewhere on the board
STEERING_2: U7.9 (IN5); also elsewhere on the board
VBAT: A2.VBAT; also elsewhere on the board
WATCHDOG: A2.D21 (A7); also elsewhere on the board

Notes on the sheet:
decoupling
Main ECU
X15
X140


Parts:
A3: TEENSY_4.1; TEENSY_LONG_EXT
A4: XB3-C-A2-UT-001; XBEE
C9, C76, C78, C80, C81, C84, C85, C100, C102, C103, C104: CAPACITOR_0603_10V_0.1UF; 0603-CAP
C11, C77, C79, C82, C83: CAPACITOR_0603_10V_1UF; 0603-CAP
D21: LED_0603_YELLOW; 0603-LED
D22: LED_0603_ORANGE; 0603-LED
D23: LED_0603_RED; 0603-LED
D28: TVS_5V; SOT-23
R14, R42: RESISTOR_0603_10K; 0603-RES
R35, R36, R37: RESISTOR_0603_60.4; 0603-RES
R43: RESISTOR_0603_2.55K; 0603-RES
U32: ADC128S022; TSSOP-16
U33, U45, U46: TCAN1051HQV-Q1; SOIC-08(NARROW,0.15")
XA1: ULTIMATE_GPS
XB1: BATTERY_HOLDER_KEYSTONE_498; 498

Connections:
3.3V: A3.3V3 (3.3V), A3.3V3@2 (3.3V), A3.3V3@3 (3.3V); also elsewhere on the board
3V3: XA1.3.3V (3V3)
24V_SENSE: D28.3 (C), R42.1, R43.2, U32.4 (IN0)
!AD4_CS: A3.D33, U32.1 (!CS!)
+3V3: A4.1 (VDD), C76.1, C77.1, C80.1, C82.1, C85.1, C102.1, C104.1, U32.13 (VLOGIC), U33.5 (VIO), U45.5 (VIO), U46.5 (VIO); also elsewhere on the board
+5V: A3.VIN, C9.1, C11.1, C78.1, C79.1, C81.1, C83.1, C84.1, C100.1, C103.1, R14.2, U32.2 (AVDD), U33.3 (VDD), U45.3 (VDD), U46.3 (VDD), XA1.VIN; also elsewhere on the board
+24V: R42.2; also elsewhere on the board
CANH_1: U33.7 (CANH); also elsewhere on the board
CANH_2: U45.7 (CANH); also elsewhere on the board
CANH_3: U46.7 (CANH); also elsewhere on the board
CANL_1: U33.6 (CANL); also elsewhere on the board
CANL_2: U45.6 (CANL); also elsewhere on the board
CANL_3: U46.6 (CANL); also elsewhere on the board
CAN_TCU_RX1: A3.D22 (A8), U33.4 (RXD)
CAN_TCU_RX2: A3.D0 ((CRX1)D0), U45.4 (RXD)
CAN_TCU_RX3: A3.D30, U46.4 (RXD)
CAN_TCU_TX1: A3.D23 (A9), U33.1 (TXD)
CAN_TCU_TX2: A3.D1 ((CTX1)D1), U45.1 (TXD)
CAN_TCU_TX3: A3.D31, U46.1 (TXD)
CURRENT: U32.5 (IN1); also elsewhere on the board
GND: A3.AGND/GND (GND), A3.GND, A3.GND@2 (GND), A4.10 (GND), C9.2, C11.2, C76.2, C77.2, C78.2, C79.2, C80.2, C81.2, C82.2, C83.2, C84.2, C85.2, C100.2, C102.2, C103.2, C104.2, D28.1 (A), R35.1, R36.1, R37.1, R43.1, U32.3 (AGND), U32.12 (GND), U33.2 (GND), U45.2 (GND), U46.2 (GND), XA1.GND, XB1.2 (MINUS); also elsewhere on the board
GPS_FIX: A3.D41 (A17), XA1.FIX
GPS_RX: A3.D14 (A0), XA1.RX (RXD)
GPS_TX: A3.D15 (A1), XA1.TX (TXD)
unnamed: D21.1 (C), R35.2
unnamed: A4.6 (PWM0/RSSI), D21.2 (A)
unnamed: A4.20 (AD0/DIO0), D22.2 (A)
unnamed: A4.15 (ASC/AD5/DIO5), D23.2 (A)
unnamed: R14.1, XA1.EN
unnamed: D22.1 (C), R37.2
unnamed: D23.1 (C), R36.2
REFERENCE: U32.6 (IN2); also elsewhere on the board
TCU_RX4: A3.D16 (A2); also elsewhere on the board
TCU_RX5: A3.D21 (A7); also elsewhere on the board
TCU_RX6: A3.D25 (A11); also elsewhere on the board
TCU_RX7: A3.D28; also elsewhere on the board
TCU_TX4: A3.D17 (A3); also elsewhere on the board
TCU_TX5: A3.D20 (A6); also elsewhere on the board
TCU_TX6: A3.D24 (A10); also elsewhere on the board
TCU_TX7: A3.D29; also elsewhere on the board
TELEM_CLK: A3.D13 ((CLK)D13), U32.16 (CLK)
TELEM_SDI: A3.D12 ((SDI)D12), U32.15 (SDO)
TELEM_SDO: A3.D11 ((SDO)D11), U32.14 (SDI)
VBAT: A3.VBAT, XA1.VBAT, XB1.1 (PLUS); also elsewhere on the board
XBDI: A3.D8, A4.3 (DIN)
XBDO: A3.D7, A4.2 (DOUT)

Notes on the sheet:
decoupling
Data Acq
Serial2
MQTT_CONN
ASSOC
RSSI
Serial3



Board: 4 copper layers, 127.0 x 152.4 mm, 216 parts (43 on the bottom side), 187 nets.

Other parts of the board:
U$5: LOGO_HYTECH_LARGE
U$9, U$10, U$11, U$12: MOUNTING_M3

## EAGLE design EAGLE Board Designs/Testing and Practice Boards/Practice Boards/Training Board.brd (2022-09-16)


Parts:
C1: CAPACITOR_0603_10V_0.082UF; 0603-CAP
C2: CAPACITOR_0603_10V_10NF; 0603-CAP
D1: LED_0603_RED; 0603-LED
R1: RESISTOR_0603_1K; 0603-RES
R2, R3: RESISTOR_0603_100K; 0603-RES
U1: LM555; SOIC-08(NARROW,0.15")
XB1: BATTERY_HOLDER_KEYSTONE_498; 498

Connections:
GND: C1.2, C2.2, R1.1, U1.1 (GND), XB1.2 (MINUS)
unnamed: C1.1, U1.5 (CONTROL)
unnamed: D1.2 (A), U1.3 (OUTPUT)
unnamed: D1.1 (C), R1.2
unnamed: R2.2, R3.1, U1.7 (DISCHARGE)
unnamed: R2.1, U1.6 (THRESHOLD)
TRIGGER: C2.1, U1.2 (TRIGGER)
VBAT: R3.2, U1.4 (!RESET), U1.8 (VCC), XB1.1 (PLUS)


Board: 2 copper layers, 22.9 x 38.1 mm, 9 parts (0 on the bottom side), 8 nets.

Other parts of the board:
U$1: LOGO_HYTECH_SMALL

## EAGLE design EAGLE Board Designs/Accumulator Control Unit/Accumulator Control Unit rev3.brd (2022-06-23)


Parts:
3.3V: LED_0603_GREEN; 0603-LED
5V: LED_0603_BLUE; 0603-LED
12V: LED_0603_RED; 0603-LED
A1: VOLTAGE_REGULATOR_MODULE_OKI-78SR_5V; OKI-78SR
C24, C33: CAPACITOR_0603_25V_10UF; 0603-CAP
C36, C103: CAPACITOR_0603_10V_4.7UF; 0603-CAP
C37: CAPACITOR_0603_10V_1UF; 0603-CAP
C100: CAPACITOR_0603_10V_10NF; 0603-CAP
C101, C104: CAPACITOR_0603_25V_1UF; 0603-CAP
C102: CAPACITOR_0603_25V_0.1UF; 0603-CAP
CURRENT_REF: TEST_POINT; MICRO_MINIATURE
CURRENT_SENSE: TEST_POINT; MICRO_MINIATURE
D8, D100, D101: TVS_15V; SOT-23
F1, F2: FUSE_0603_.75A; 0603-FUSE
J2: CONNECTOR-8_MF_T_V_; MOLEX_MICROFIT_PTH_VERTICAL_08_DUAL
J3: CONNECTOR-14_MF_T_V_; MOLEX_MICROFIT_PTH_VERTICAL_14_DUAL
J5: CONNECTOR-12_MF_T_V_; MOLEX_MICROFIT_PTH_VERTICAL_12_DUAL
J6: CONNECTOR-CAN_μF_S_RA_; MOLEX_MICROFIT_SMD_RIGHTANGLE_04_DUAL
J100: CONNECTOR-8_S_S; FLEX_STACK_PTH_08_DUAL
Q100, Q101: TRANSISTOR_N_MOS__PMV15ENEA; SOT-23
R10, R11, R19: RESISTOR_0603_1K; 0603-RES
R15: RESISTOR_0603_2.2K; 0603-RES
R61, R62: RESISTOR_0603_2K; 0603-RES
R100, R101, R102, R106: RESISTOR_0603_10K; 0603-RES
R103, R104: RESISTOR_0603_10; 0603-RES
R105: RESISTOR_0603_43K; 0603-RES
TP_3.3V, TP_5V, TP_12V: TEST_POINT; MICRO_MINIATURE
TP_GND: TEST_POINT; MICRO_MINIATURE
TP_TSAL_GREEN: TEST_POINT; MICRO_MINIATURE
TP_TSAL_RED: TEST_POINT; MICRO_MINIATURE
TSAL_GREEN: LED_0603_GREEN; 0603-LED
TSAL_RED: LED_0603_RED; 0603-LED
U26: VOLTAGE_REGULATOR_SOT223_3.3V; SOT223
U100: ADG1423; MSOP-10
U101: LM555; SOIC-08(NARROW,0.15")
XF1: FUSE_HOLDER_MINIBLADEPTH; 3568

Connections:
12VIN: D8.3 (C), J5.1, XF1.1, XF1.2 (1)
60V_THRESHOLD: U100.6 (IN), U100.7 (IN); also elsewhere on the board
+3V3: 3.3V.2 (A), C36.1, TP_3.3V.1, U26.2 (OUT), U26.4 (OUT); also elsewhere on the board
+5V: 5V.2 (A), A1.3 (OUT), C33.1, C37.1, J3.5, TP_5V.1, U26.3 (IN); also elsewhere on the board
+12V: 12V.2 (A), A1.1 (IN), C24.1, C101.1, C102.1, C104.1, J2.1, J3.7, J6.1 (+12V), J100.5, R61.1, R62.1, R106.2, TP_12V.1, U100.1 (S), U100.2 (S), U100.5 (VDD), U101.8 (VCC), XF1.3 (2), XF1.4 (2); also elsewhere on the board
ACCUMULATOR_GND: J2.7, J3.14
AIR2-: J3.13; also elsewhere on the board
AMS_OK: J5.6; also elsewhere on the board
BSPD_CURRENT: J5.10; also elsewhere on the board
CANH: J3.3, J5.9, J6.4 (CANH); also elsewhere on the board
CANL: J3.2, J5.8, J6.3 (CANL); also elsewhere on the board
CHASSIS_GND: J2.6, J5.11
CURRENT: CURRENT_SENSE.1, J3.8; also elsewhere on the board
CURRENT_REF: CURRENT_REF.1, J3.9; also elsewhere on the board
GND: A1.2 (GND), C24.2, C33.2, C36.2, C37.2, C100.2, C101.2, C102.2, C103.2, C104.2, D8.1 (A), D100.1 (A), D101.1 (A), J2.4, J3.4, J3.6, J3.11, J5.2, J6.2 (GND), J100.8, Q100.2 (S), Q101.2 (S), R10.1, R11.1, R15.1, R19.1, R100.1, R101.2, R102.2, TP_GND.1, U26.1 (GND), U100.4 (GND), U100.8 (GND), U101.1 (GND); also elsewhere on the board
IMD_OK: J5.7; also elsewhere on the board
ISO_PACK+: J100.1; also elsewhere on the board
ISO_PACK-: J100.2; also elsewhere on the board
ISO_TS+: J100.3; also elsewhere on the board
ISO_TS-: J100.4; also elsewhere on the board
MHS: J2.3, R15.2; also elsewhere on the board
unnamed: 3.3V.1 (C), R19.2
unnamed: 5V.1 (C), R10.2
unnamed: C103.1, R105.1, U101.2 (TRIGGER), U101.6 (THRESHOLD)
unnamed: C100.1, U101.5 (CONTROL)
unnamed: R105.2, R106.1, U101.7 (DISCHARGE)
unnamed: 12V.1 (C), R11.2
unnamed: D100.3 (C), R102.1, R104.1, TP_TSAL_GREEN.1, U100.9 (D)
unnamed: D101.3 (C), R101.1, R103.1, TP_TSAL_RED.1, U101.3 (OUTPUT)
unnamed: R62.2, TSAL_GREEN.2 (A)
unnamed: F2.1, J5.3
unnamed: F1.1, J5.4
unnamed: R61.2, TSAL_RED.2 (A)
unnamed: Q100.1 (G), R103.2
unnamed: Q101.1 (G), R104.2
OKHS: J2.2; also elsewhere on the board
PRECHARGE_OK: J100.7; also elsewhere on the board
SHDN: J3.10, J3.12, J5.5, J100.6
TIMER_EN: R100.2, U100.10 (D), U101.4 (!RESET)
TSAL_GREEN: F2.2, Q101.3 (D), TSAL_GREEN.1 (C)
TSAL_RED: F1.2, Q100.3 (D), TSAL_RED.1 (C)

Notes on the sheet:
Josh Kirshenbaum
Connectors
ACU to TSB connections
Power, CAN, TSAL, Shutdown Signals
Power Fusing and Regulation
SHDN connnects directly to AIR+, AIR- connects directly to GND
TSAL Circuitry
555 Timer Astable Mode Frequency: 3.529 Hz Duty Cycle: 50.57% Rules say 2-5Hz
SHDN connnects directly to AIR+
Energy Meter, Current Sensor Accumulator GND, both AIR+ and -
IMD


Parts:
AMS_OK: LED_0603_GREEN; 0603-LED
D2: TVS_8V; SOT-23
IMD_OK: LED_0603_ORANGE; 0603-LED
OKHS: LED_0603_YELLOW; 0603-LED
Q1: TRANSISTOR_N_MOS__PMV15ENEA; SOT-23
R2, R7, R8: RESISTOR_0603_2K; 0603-RES
R3, R9: RESISTOR_0603_1K; 0603-RES
R6, R12, R14: RESISTOR_0603_10K; 0603-RES
R13: RESISTOR_0603_10; 0603-RES
TP_AMS_OK: TEST_POINT; MICRO_MINIATURE
TP_IMD_OK: TEST_POINT; MICRO_MINIATURE
U1, U2: RELAY_SOLIDSTATE_NO; DIP-4

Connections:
+12V: R7.2, U1.4 (CONTACT2), U2.4 (CONTACT2); also elsewhere on the board
AMS_OK: AMS_OK.2 (A), R12.2, TP_AMS_OK.1, U2.3 (CONTACT1); also elsewhere on the board
AMS_OK_3.3V: D2.3 (C), R13.1, R14.1; also elsewhere on the board
GND: D2.1 (A), Q1.2 (S), R2.1, R3.1, R6.1, R9.1, R12.1, R14.2, U1.2 (CONTROL-); also elsewhere on the board
IMD_OK: IMD_OK.2 (A), R6.2, TP_IMD_OK.1, U1.3 (CONTACT1); also elsewhere on the board
unnamed: R8.2, U1.1 (CONTROL+)
unnamed: OKHS.1 (C), R9.2
unnamed: R7.1, U2.1 (CONTROL+)
unnamed: AMS_OK.1 (C), R3.2
unnamed: Q1.3 (D), U2.2 (CONTROL-)
unnamed: IMD_OK.1 (C), R2.2
unnamed: Q1.1 (G), R13.2
OKHS: OKHS.2 (A), R8.1; also elsewhere on the board

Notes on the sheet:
Josh Kirshenbaum
Shutdown Signal Buffering/Amplification

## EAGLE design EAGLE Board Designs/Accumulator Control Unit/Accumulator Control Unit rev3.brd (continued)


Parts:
C13, C14, C15, C16, C17, C18, C19, C26, C27, C28: CAPACITOR_0603_10V_0.1UF; 0603-CAP
D4: TVS_8V; SOT-23
PACK+_OUT_TEST: TEST_POINT; MICRO_MINIATURE
PRECHARGE_OK: LED_0603_RED; 0603-LED
PRECHARGE_OK_TEST: TEST_POINT; MICRO_MINIATURE
Q2: TRANSISTOR_N_MOS__PMV15ENEA; SOT-23
R16: RESISTOR_0603_1K; 0603-RES
R17, R29, R37, R42, R43, R44, R50, R52, R69, R71, R73, R81: RESISTOR_0603_10K; 0603-RES
R18: RESISTOR_0603_10; 0603-RES
R28: RESISTOR_0603_470; 0603-RES
R38, R51, R53, R66, R67, R74, R75: RESISTOR_0603_11.5K; 0603-RES
R39: RESISTOR_0603_84.5K; 0603-RES
R40, R45, R47, R54, R64: RESISTOR_0603_DNP; 0603-RES
R41, R48: RESISTOR_0603_10.2K; 0603-RES
R46: RESISTOR_0603_215K; 0603-RES
R49, R63: RESISTOR_0603_4.12K; 0603-RES
R65, R68, R72, R76: RESISTOR_0603_10.5K; 0603-RES
R70: RESISTOR_0603_11.3K; 0603-RES
TS+_OUT_TEST: TEST_POINT; MICRO_MINIATURE
U8: RELAY_SOLIDSTATE_NO; DIP-4
U11, U13, U15, U17, U21, U22, U23: OPAMP_1_CHANNEL_OPA991; SC-70-5
U12, U14, U16: LOGICGATE_AND_DCK3; SC-70-5

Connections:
0.95X_DIV: R45.2, R46.2, R70.1, U13.3 (VIN-)
0.5989V_DIV: R38.2, R39.1, R40.2, U21.3 (VIN-)
2.5_DIV: R51.2, R53.1, R54.2, U17.3 (VIN-)
3.56V_DIV_A: R41.2, R63.1, R64.1, U11.1 (VIN+)
3.56V_DIV_B: R47.1, R48.2, R49.1, U15.1 (VIN+)
60V_THRESHOLD: R37.2, U21.4 (VOUT); also elsewhere on the board
+5V: C13.1, C14.1, C15.1, C16.1, C17.1, C18.1, C19.1, C26.1, C27.1, C28.1, R39.2, R47.2, R49.2, R53.2, R63.2, R64.2, U8.4 (CONTACT2), U11.5 (VDD), U12.5 (VDD), U13.5 (VDD), U14.5 (VDD), U15.5 (VDD), U16.5 (VDD), U17.5 (VDD), U21.5 (VDD), U22.5 (VDD), U23.5 (VDD); also elsewhere on the board
AIR2-: Q2.3 (D); also elsewhere on the board
GND: C13.2, C14.2, C15.2, C16.2, C17.2, C18.2, C19.2, C26.2, C27.2, C28.2, D4.1 (A), PRECHARGE_OK.1 (C), Q2.2 (S), R17.2, R29.1, R37.1, R38.1, R40.1, R41.1, R42.1, R43.1, R44.1, R45.1, R46.1, R48.1, R50.1, R51.1, R52.1, R54.1, R68.2, R69.1, R71.1, R73.1, R76.2, R81.1, U8.2 (CONTROL-), U11.2 (GND), U12.3 (GND), U13.2 (GND), U14.3 (GND), U15.2 (GND), U16.3 (GND), U17.2 (GND), U21.2 (GND), U22.2 (GND), U23.2 (GND); also elsewhere on the board
HV+_OUT_OK: R43.2, U12.4 (OUT), U14.1 (IN1)
ISO_PACK+: R75.1; also elsewhere on the board
ISO_PACK-: R73.2, R74.1; also elsewhere on the board
ISO_TS+: R67.1; also elsewhere on the board
ISO_TS-: R66.1, R81.2; also elsewhere on the board
unnamed: PRECHARGE_OK.2 (A), R16.1
unnamed: Q2.1 (G), R18.2
unnamed: R67.2, R68.1, U22.1 (VIN+)
unnamed: R65.1, R66.2, U22.3 (VIN-)
unnamed: R75.2, R76.1, U23.1 (VIN+)
unnamed: R72.1, R74.2, U23.3 (VIN-)
unnamed: R28.1, U14.4 (OUT)
unnamed: R28.2, U8.1 (CONTROL+)
PACK+_OUT: PACK+_OUT_TEST.1, R70.2, R71.2, R72.2, U15.3 (VIN-), U17.1 (VIN+), U23.4 (VOUT); also elsewhere on the board
PRECHARGE+_OUT_OK: R29.2, U14.2 (IN2), U16.4 (OUT)
PRECHARGE_OK: D4.3 (C), PRECHARGE_OK_TEST.1, R16.2, R17.1, R18.1, U8.3 (CONTACT1); also elsewhere on the board
PRECHARGE_REACHED: R44.2, U12.2 (IN2), U13.4 (VOUT)
TS+_OUT: R65.2, R69.2, TS+_OUT_TEST.1, U11.3 (VIN-), U13.1 (VIN+), U21.1 (VIN+), U22.4 (VOUT); also elsewhere on the board
TS+_OUT_OV_OK: R42.2, U11.4 (VOUT), U12.1 (IN1)
V_PACK_REF_OV_OK: R50.2, U15.4 (VOUT), U16.1 (IN1)
V_PACK_REF_UV_OK: R52.2, U16.2 (IN2), U17.4 (VOUT)

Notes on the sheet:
60V threshold check
At 60V on the input, the output is 0.5999986V. To ensure that we trip by 60V, the divider has been downsized to 0.5989V instead of nominal 0.6V. The DNP resistor is included for ease of tuning the voltage divider.
0.95x
low side switches shutdown current across precharge relay
Josh Kirshenbaum
AIR2- Low Side Switching with PRECHARGE_OK


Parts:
BSPD_CURRENT: TEST_POINT; MICRO_MINIATURE
C2, C8, C20, C29, C35: CAPACITOR_0603_25V_0.1UF; 0603-CAP
C3, C9, C10, C11, C21, C22, C30, C31: CAPACITOR_0603_10V_0.1UF; 0603-CAP
C4, C12, C23, C32: CAPACITOR_0603_10V_680PF; 0603-CAP
R22, R30, R55, R59, R77: RESISTOR_0603_10K; 0603-RES
R23, R31, R56, R78: RESISTOR_0603_12K; 0603-RES
R57: RESISTOR_0603_1K; 0603-RES
R58: RESISTOR_0603_1.4K; 0603-RES
U3, U9, U18, U20, U24: OPAMP_1_CHANNEL_OPA991; SC-70-5
U4, U10, U19, U25: MAX7404; SOIC-08(NARROW,0.15")

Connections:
+3V3: C2.1, C8.1, C9.1, C10.1, C20.1, C21.1, C29.1, C30.1, U3.5 (VDD), U4.4 (VDD), U4.7 (!SHDN), U9.5 (VDD), U10.4 (VDD), U10.7 (!SHDN), U18.5 (VDD), U19.4 (VDD), U19.7 (!SHDN), U24.5 (VDD), U25.4 (VDD), U25.7 (!SHDN); also elsewhere on the board
+12V: C35.1, U20.5 (VDD); also elsewhere on the board
BSPD_CURRENT: BSPD_CURRENT.1, R58.2, U20.4 (VOUT); also elsewhere on the board
CURRENT: R30.1, R59.2, U20.1 (VIN+); also elsewhere on the board
CURRENT_BUFFER: U9.3 (VIN-), U9.4 (VOUT), U10.2 (IN)
CURRENT_FILTERED: U10.5 (OUT); also elsewhere on the board
CURRENT_REF: R22.1; also elsewhere on the board
CURRENT_REF_BUFFER: U3.3 (VIN-), U3.4 (VOUT), U4.2 (IN)
CURRENT_REF_FILTERED: U4.5 (OUT); also elsewhere on the board
GND: C2.2, C3.2, C4.2, C8.2, C9.2, C10.2, C11.2, C12.2, C20.2, C21.2, C22.2, C23.2, C29.2, C30.2, C31.2, C32.2, C35.2, R23.2, R31.2, R56.2, R57.1, R59.1, R78.2, U3.2 (GND), U4.3 (GND), U9.2 (GND), U10.3 (GND), U18.2 (GND), U19.3 (GND), U20.2 (GND), U24.2 (GND), U25.3 (GND); also elsewhere on the board
unnamed: R57.2, R58.1, U20.3 (VIN-)
unnamed: C31.1, U25.1 (COM), U25.6 (OS)
unnamed: C32.1, U25.8 (CLK)
unnamed: R77.2, R78.1, U24.1 (VIN+)
unnamed: C11.1, U10.1 (COM), U10.6 (OS)
unnamed: C12.1, U10.8 (CLK)
unnamed: R30.2, R31.1, U9.1 (VIN+)
unnamed: C3.1, U4.1 (COM), U4.6 (OS)
unnamed: C4.1, U4.8 (CLK)
unnamed: R22.2, R23.1, U3.1 (VIN+)
unnamed: C22.1, U19.1 (COM), U19.6 (OS)
unnamed: C23.1, U19.8 (CLK)
unnamed: R55.2, R56.1, U18.1 (VIN+)
PACK+_BUFFER: U18.3 (VIN-), U18.4 (VOUT), U19.2 (IN)
PACK+_FILTERED: U19.5 (OUT); also elsewhere on the board
PACK+_OUT: R55.1; also elsewhere on the board
TS+_OUT: R77.1; also elsewhere on the board
TS+_OUT_BUFFER: U24.3 (VIN-), U24.4 (VOUT), U25.2 (IN)
TS+_OUT_FILTERED: U25.5 (OUT); also elsewhere on the board

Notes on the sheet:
Josh Kirshenbaum
Analog Filtering


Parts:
A2: TEENSY_4.0; TEENSY_SHORT
C1, C6: CAPACITOR_0603_10V_10NF; 0603-CAP
C5, C34, C38: CAPACITOR_0603_10V_0.1UF; 0603-CAP
C25: CAPACITOR_0603_10V_4.7NF; 0603-CAP
C39: CAPACITOR_0603_10V_1UF; 0603-CAP
D3, D7, D9, D10, D11: TVS_15V; SOT-23
J1: CONNECTOR-2_MF_T_V_; MOLEX_MICROFIT_PTH_VERTICAL_02_SINGLE
J4: JUMPER__1X02; 1X02
R1: RESISTOR_0603_120; 0603-RES
R4, R20, R79, R108, R110: RESISTOR_0603_; 0603-RES
R5, R80, R107: RESISTOR_0603_12K; 0603-RES
R21: RESISTOR_0603_15K; 0603-RES
R24, R25: RESISTOR_0603_1K; 0603-RES
R26, R27, R82: RESISTOR_0603_10K; 0603-RES
R32, R33: RESISTOR_0603_2K; 0603-RES
R34, R35: RESISTOR_0603_470; 0603-RES
R36, R60: RESISTOR_0603_60.4; 0603-RES
R109: RESISTOR_0603_18.7K; 0603-RES
T1: TRANSFORMER_HM2112ZNLT_AIRGAP; HM2112ZNLT_AIRGAP
TD+: TEST_POINT; MICRO_MINIATURE
TD-: TEST_POINT; MICRO_MINIATURE
TEENSY_OK: LED_0603_RED; 0603-LED
U5: LTC6820; MSOP-16
U6: LOGICGATE_BUFFER; SC-70-5
U7: ADM8316WBX30; SOT-23-5
U27: TCAN1051HQV-Q1; SOIC-08(NARROW,0.15")
WATCHDOG: LED_0603_BLUE; 0603-LED
WATCHDOG_OK: TEST_POINT; MICRO_MINIATURE

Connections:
12V_SCALED_3.3V: A2.D19 (A5), R107.1, R108.2
+3V3: A2.3.3V, C5.1, C6.2, C34.2, R32.2, R33.2, U5.1 (VDD), U5.6 (VLOGIC), U5.7 (VDD), U5.8 (VDD), U5.9 (VDD), U5.12 (VDD), U6.5 (VDD), U27.5 (VIO); also elsewhere on the board
+5V: A2.VIN, C38.2, C39.2, U27.3 (VDD); also elsewhere on the board
+12V: D7.3 (C), R108.1; also elsewhere on the board
AMS_OK_3.3V: U6.4 (OUT); also elsewhere on the board
BSPD_CURRENT: D9.3 (C), R79.1; also elsewhere on the board
BSPD_CURRENT_TEENSY: A2.D22 (A8), R79.2, R80.1
CANH: J4.1, U27.7 (CANH); also elsewhere on the board
CANH/1.3B: J4.2, R36.2
CANL: R60.2, U27.6 (CANL); also elsewhere on the board
CS_LTC_6820: A2.D10 ((CS)D10), U5.5 (!CS)
CURRENT_FILTERED: A2.D21 (A7); also elsewhere on the board
CURRENT_REF_FILTERED: A2.D20 (A6); also elsewhere on the board
GND: A2.AGND/GND (GND), A2.GND, C1.2, C5.2, C6.1, C25.1, C34.1, C38.1, C39.1, D3.1 (A), D7.1 (A), D9.1 (A), D10.1 (A), D11.1 (A), R5.2, R21.2, R24.2, R26.1, R80.2, R82.1, R107.2, R110.2, TEENSY_OK.1 (C), U5.13 (GND), U5.14 (GND), U6.3 (GND), U7.2 (GND), U27.2 (GND), U27.8 (S), WATCHDOG.1 (C); also elsewhere on the board
IM: T1.10 (TD-), U5.10 (IM)
IMD_OK: D10.3 (C), R4.1; also elsewhere on the board
IMD_OK_TEENSY: A2.D16 (A2), R4.2, R5.1
IP: T1.12 (TD+), U5.11 (IP)
MHS: D3.3 (C), R20.1; also elsewhere on the board
MHS_TEENSY: A2.D14 (A0), R20.2, R21.1
unnamed: A2.D11 ((SDO)D11), R33.1, U5.2 (SDI)
unnamed: R82.2, U6.2 (IN), U7.1 (!RESET!)
unnamed: C25.2, R36.1, R60.1
unnamed: A2.D0 ((CRX1)D0), A2.D4, U27.4 (RXD)
unnamed: A2.D1 ((CTX1)D1), A2.D3, U27.1 (TXD)
unnamed: R25.1, U5.16 (IBIAS)
unnamed: R24.1, R25.2, U5.15 (ICMP)
unnamed: C1.1, T1.11 (TCT)
unnamed: A2.D12 ((SDI)D12), R32.1, U5.3 (SDO)
unnamed: A2.D13 ((CLK)D13), U5.4 (CLK)
unnamed: R34.1, WATCHDOG.2 (A)
unnamed: R35.1, TEENSY_OK.2 (A)
unnamed: R27.2, U7.3 (!MR!)
PACK+_FILTERED: A2.D17 (A3); also elsewhere on the board
PRECHARGE_OK: D11.3 (C), R109.1; also elsewhere on the board
PRECHARGE_OK_TEENSY: A2.D15 (A1), R109.2, R110.1
TD+: J1.1, R1.2, T1.1 (MX+), TD+.1
TD-: J1.2, R1.1, T1.3 (MX-), TD-.1
TEENSY_OK: A2.D6, R27.1, R35.2, U7.5 (VDD)
TS+_OUT_FILTERED: A2.D18 (A4); also elsewhere on the board
WATCHDOG_INPUT: A2.D5, R26.2, R34.2, U7.4 (WDI), WATCHDOG_OK.1

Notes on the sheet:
12V to 3.3V
5V to 3.3V
Watchdog Timer
Voltage Dividers
LTC6820 and Transformer
10V to 3.3V



Board: 4 copper layers, 186.7 x 143.9 mm, 241 parts (24 on the bottom side), 117 nets.

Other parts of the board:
U$1, U$5, U$8, U$9, U$10, U$11, U$12, U$14, U$16, U$17, U$18, U$19, U$20: MOUNTING_M3
U$2, U$7: GLV
U$3, U$6: TS
U$4, U$100: HV_LARGE
U$13: LOGO_HYTECH_EXTRA_LARGE
U$15: LOGO_GT_0.50"

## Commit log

2022-09-16 created training boards
    [Training Board.brd, Training Board.sch]
2022-09-16 fixed silkscreen
    [Training Board.brd]
2022-11-01 playground filter board schematics
    [MainECU rev11.brd, MainECU rev11.sch, playgroundFilter.sch]
2022-11-03 Prototype filter schematic
    my eagle is scuffed :(
    [Filter Board rev1.sch, playgroundFilter.sch]
2022-11-03 Updated Filter Board Schematic
    [Filter Board rev1.sch]
2022-11-04 added second order rc filter
    [Filter Board rev1.sch]
2022-11-08 Grouped components together!
    [Filter Board rev1.brd, Filter Board rev1.sch]
2022-11-08 Fixed width and added ground plane!
    [Filter Board rev1.brd]
2022-11-11 Placing things on Board!
    [Filter Board rev1.brd]
2022-11-11 I suck at this
    [Filter Board rev1.brd]
2022-11-11 fixed wire widths
    [Filter Board rev1.brd]
2022-11-13 Update Filter Board
    [Filter Board rev1.brd]
2022-11-14 Next Step: Compact
    [Filter Board rev1.brd]
2022-11-14 compact filter
    [Filter Board rev1.brd]
2022-11-15 I'll take another look tomorrow
    Improved filter and wire alignment
    [Filter Board rev1.brd]
2022-11-16 Large Logo for Large Frequencies
    to be filtered later...
    [Filter Board rev1.brd]
2022-11-17 quick fix
    [Filter Board rev1.brd, Filter Board rev1.sch]
2022-11-17 inverted design
    [Filter Board rev1.brd, Filter Board rev1.sch]
2022-11-17 I am awful at eagle
    [Filter Board rev1.brd]
2022-11-18 GOt it
    [Filter Board rev1.brd]
2022-11-18 vector -> proportional
    [Filter Board rev1.sch]
2022-11-18 Updated for HyTech Default DRC
    [Filter Board rev1.brd]
2022-11-20 ordering file
    [Filter Board rev1.csv]
2022-12-05 simplified passive filters
    [Filter Board rev2.brd, Filter Board rev2.sch]
2022-12-05 fixed drc
    [Filter Board rev2.brd]
2022-12-11 first progress
    [track-testing-rev1.sch]
2022-12-11 enough for two strain gauges
    waiting to find datasheet on infrared sensors.
    [track-testing-rev1.brd, track-testing-rev1.sch]
2022-12-12 passes drc as is
    [track-testing-rev1.brd, track-testing-rev1.sch]
2022-12-23 10 strain gauges and aero uart, passes drc
    [track-testing-rev1.brd, track-testing-rev1.sch]
2023-04-07 track testing board
    [track-testing-rev1.brd, track-testing-rev1.sch]
